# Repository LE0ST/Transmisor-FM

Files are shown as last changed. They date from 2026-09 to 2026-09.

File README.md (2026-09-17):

# Low-Power FM Broadcast Transmitter (88–108 MHz)

Low-power analog FM transmitter for the commercial VHF band (88–108 MHz). This project integrates analog RF stages, Altium Designer SPICE simulations, 4NEC2 antenna modeling, and an EasyEDA PCB implementation.

## Demonstration / Project Gallery

| 1. Physical Prototype (Assembled PCB) | 2. EasyEDA PCB 3D Design |
| :---: | :---: |
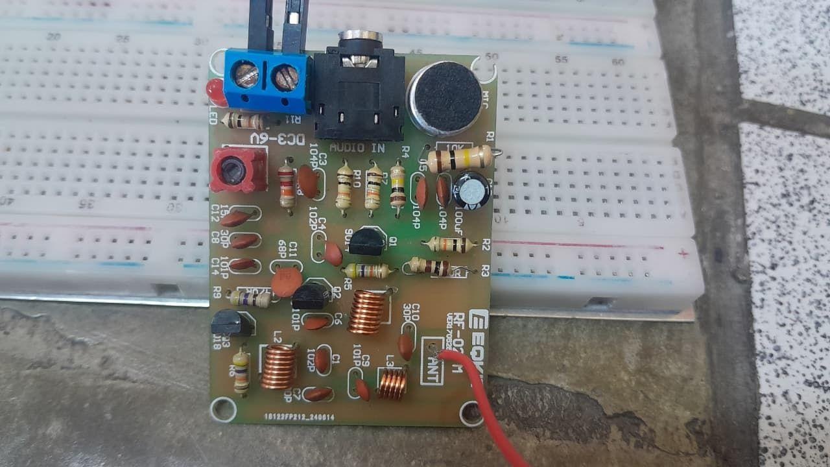
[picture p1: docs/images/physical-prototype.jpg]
Physical Prototype
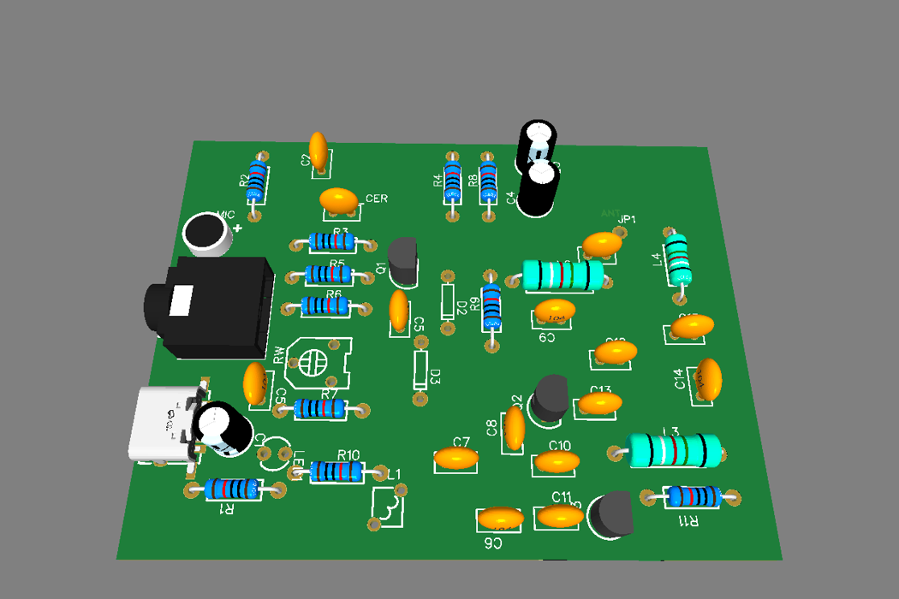
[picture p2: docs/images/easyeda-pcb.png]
EasyEDA PCB Design
|  |  |

| 3. RF Circuit Schematic | 4. 4NEC2 Antenna Radiation Pattern | 5. SPICE Transient Simulation |
| :---: | :---: | :---: |
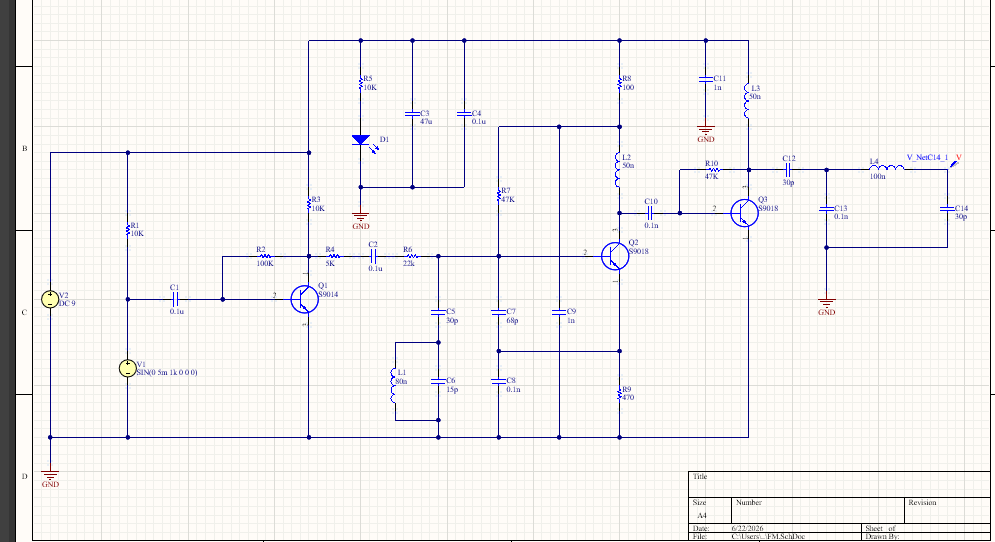
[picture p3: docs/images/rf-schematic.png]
RF Schematic
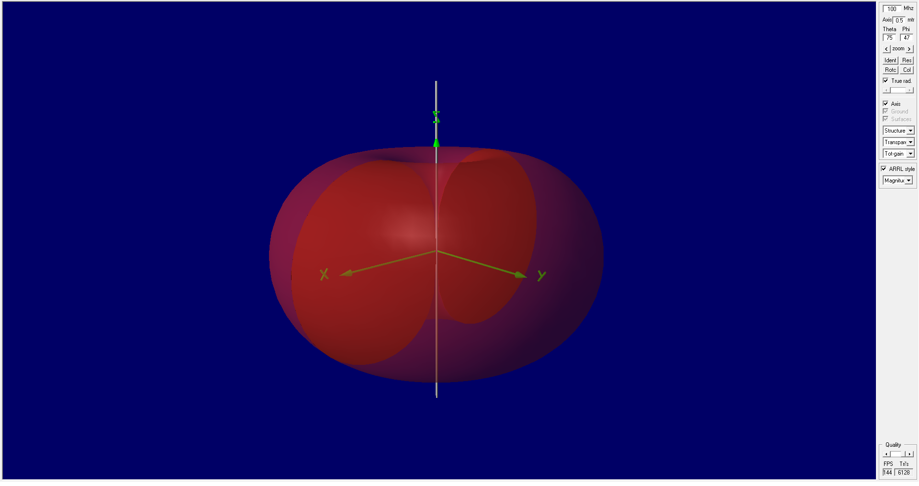
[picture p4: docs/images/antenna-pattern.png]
Antenna Pattern
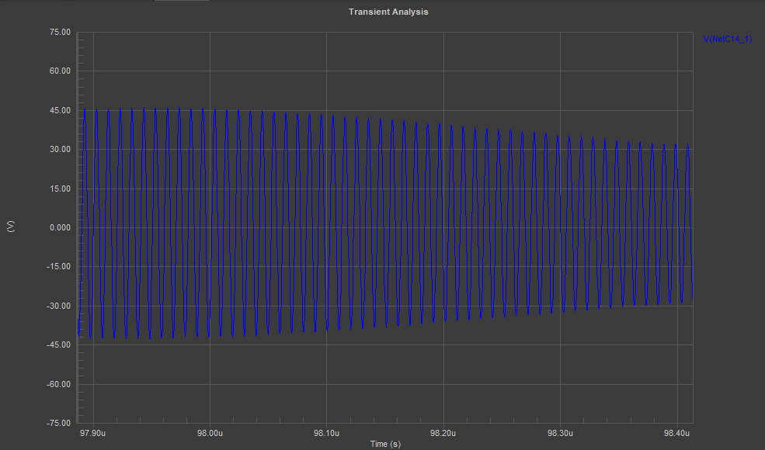
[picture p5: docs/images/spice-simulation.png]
SPICE Simulation
|  |  |  |

## Project Overview

This system was designed, simulated, and physically implemented to transmit audio over the commercial FM broadcast band. It is built with discrete analog components, operating from a 5 V power supply (Arduino Nano) and utilizing high-frequency bipolar junction transistors (BJTs).

## System Architecture

```mermaid
flowchart LR
    A[Audio Input] --> B[S9014 Common-Emitter Preamplifier]
    B --> C[S9018 Colpitts Oscillator / FM Modulator]
    C --> D[S9018 Class-C RF Amplifier]
    D --> E[Pi LC Output Network]
    E --> F[Antenna]
```

## RF Signal Chain

### 1. Audio Preamplifier
- **Topology:** Common-Emitter
- **Active Component:** S9014 (NPN BJT)
- **Performance:** Provides a theoretical voltage gain of approximately Av ≈ 49.3 dB at the 9 V design operating point.

### 2. Colpitts Oscillator & FM Modulator
- **Topology:** Colpitts LC Oscillator
- **Active Component:** S9018 (NPN RF BJT)
- **Modulation:** Direct reactive FM modulation via base-emitter junction capacitance variation.
- **Performance:** Theoretical frequency of 84.116 MHz (CALCULATED), tuned physically to 94.6 MHz (OBSERVED) in the prototype. Theoretical FM sensitivity calculated as kf ≈ 66.08 kHz/V.

### 3. Class-C RF Amplifier
- **Topology:** Common-Emitter with inductive collector load (Class-C)
- **Active Component:** S9018 (NPN RF BJT)
- **Function:** Class-C RF amplification stage intended to improve isolation from load variations.

### 4. Pi LC Output Network
- **Topology:** Passive Pi LC bandpass filter
- **Performance:** Designed for a theoretical center frequency of f0 = 101.94 MHz and a theoretical bandwidth of 19.89 MHz (CALCULATED), targeting a nominal 50 Ω load match.

### 5. Antenna
- **Design:** Modeled as a theoretical half-wave dipole at 100 MHz in 4NEC2 (SIMULATED).
- **Physical Test:** Field range tests utilized a monopole antenna (OBSERVED).

## Theoretical vs Simulated vs Experimental Results

| Parameter | Value | Evidence Type | Source |
|---|---|---|---|
| Operating target band | 88–108 MHz | DESIGN SPECIFICATION | Project Requirements |
| Theoretical oscillator frequency | 84.116 MHz | CALCULATED | Analytical Model |
| SPICE oscillator frequency | 100 MHz | SIMULATED | Altium SPICE |
| Physical prototype frequency | 94.6 MHz | OBSERVED | Commercial FM receiver |
| Audio voltage gain (Av) | 49.3 dB | CALCULATED at 9 V design point | Analytical Model |
| FM sensitivity (kf) | 66.08 kHz/V | CALCULATED | Analytical Model |
| Theoretical RF output power | 74.28 mW | CALCULATED | Analytical Model |
| Friis analysis transmit-power assumption | ~60 mW | ESTIMATED / ASSUMED | Theoretical analysis |
| SPICE RF output power | 6.57 mW | SIMULATED | Altium SPICE |
| Pi network center frequency | 101.94 MHz | CALCULATED | Analytical Model |
| Pi network bandwidth | 19.89 MHz | CALCULATED | Analytical Model |
| 4NEC2 dipole length | 1.425 m | SIMULATION MODEL | 4NEC2 DIPOLE.nec |
| 4NEC2 gain | 2.14 dBi | SIMULATED | 4NEC2 |
| 4NEC2 VSWR | 1.506 | SIMULATED | 4NEC2 |
| 4NEC2 return loss | 13.884 dB | SIMULATED | 4NEC2 |
| Observed reception range | up to approximately 50 m | OBSERVED with commercial FM receiver | Field observation |

## SPICE Simulation
Circuit and SPICE simulations were performed in **Altium Designer**. Mixed-signal simulations including Transient, AC Sweep, and Fourier analyses were used to characterize each stage's frequency response, gain, and spectral content.

## Antenna Modeling with 4NEC2
The radiation characteristics of a half-wave dipole were modeled using **4NEC2**. The theoretical simulation model exhibited a total length of 1.425 m, yielding a simulated gain of 2.14 dBi, a VSWR of 1.506, and a return loss of 13.884 dB at 100 MHz in free space. Field tests used a physical monopole antenna.

## PCB Design & Fabrication
The PCB was designed in **EasyEDA**. Manufacturing Gerbers were exported, and the physical board was fabricated using a phenolic copper-clad board and ferric chloride etching. The board was then hand-assembled and soldered. *(Note: The original EasyEDA editable design files are not currently archived in this repository; only the Gerber manufacturing outputs are included.)*

## Physical Prototype
The physical prototype was powered by a 5 V supply from an Arduino Nano.

## Experimental Observations
During physical validation:
- The supply voltage was confirmed at 5 V with a multimeter.
- The transmitter was tuned to approximately 94.6 MHz.
- FM audio reception was observed up to approximately 50 m using a commercial FM receiver.

## Technical Documentation

The complete sanitized technical report is available here:

[View the Technical Report (PDF)](docs/Informe_Tecnico_Transmisor_FM_PUBLIC.pdf)

The public version preserves the engineering content while removing private academic identifiers.

## Bill of Materials
| Component | Value/Part | Stage |
|---|---|---|
| Transistor | S9014 | Audio Preamp |
| Transistor | S9018 | Oscillator & RF Amp |
| Inductor | Adjustable Ferrite Core | LC Tank |
| Inductor | Fixed RF Inductors | Buffer & Filter |
| Capacitors | Ceramic (various) | Signal Coupling, Tank, Filter |
| Resistors | Carbon Film (various) | Biasing |
| PCB | Phenolic copper-clad | Base |

## Repository Structure
```text
low-power-fm-transmitter/
├── docs/
│   ├── Informe_Tecnico_Transmisor_FM_PUBLIC.pdf
│   └── images/
├── hardware/
│   ├── altium/
│   └── fabrication/gerber/
├── simulation/
│   ├── antenna_4nec2/
│   ├── captures/
│   └── spice/
└── README.md
```

## Engineering Limitations
- **Frequency Pulling:** While the Class-C buffer was intended to isolate the oscillator, frequency pulling was still observed in the physical prototype, indicating that isolation was incomplete.
- **Power Supply Mismatch:** Design calculations assumed a 9 V supply, whereas the physical prototype operated at 5 V, leading to differences between theoretical operating points and physical behavior.
- **Antenna Divergence:** While a half-wave dipole was simulated in 4NEC2, a telescopic monopole was utilized for physical range tests.
- **Instrument Limitations:** Direct RF output power, spectral purity, and antenna impedance/VSWR were not characterized with an RF power meter, oscilloscope, or spectrum analyzer.

## Academic Context & Authors
This project was developed as a seven-member university group project for the Analog Communications course in Electronic Engineering at Universidad Nacional Mayor de San Marcos (UNMSM).

**Authors:**
- Purihuamán Rivera, Juan Matías
- Saenz Burga, Alexander Ricardo
- Yactayo Tolentino, Leonardo Sait
- Mestanza Salazar, Elias Fernando
- Huaraca Pariona, Jose Miguel
- Gamarra Galarza, Nayely Dayana
- Condori Ancco, Marco Antonio

*(Individual contribution breakdown is not established by the repository history.)*

## License

Licensing terms have not yet been specified.

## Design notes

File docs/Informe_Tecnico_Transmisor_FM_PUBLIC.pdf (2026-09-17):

## Universidad Nacional Mayor de San Marcos

Universidad del Perú, Decana de América Facultad de Ingeniería Electrónica & Eléctrica Escuela Académica Profesional de Ingeniería Electrónica

Mg. Hansel Martínez Odiaga | Página N°01 | 2026—I

## COMUNICACIÓN ANALÓGICA

### TRABAJO ACADÉMICO

PROYECTO FINAL DE INVESTIGACIÓN E IMPLEMENTACIÓN DE TRANSMISOR FM

## Integrantes

APELLIDOS & NOMBRES | CÓDIGO | GRUPO
Purihuamán Rivera, Juan Matías | [REDACTED] | N°01
Saenz Burga, Alexander Ricardo | [REDACTED]
Yactayo Tolentino, Leonardo Sait | [REDACTED]
Mestanza Salazar, Elias Fernando | [REDACTED]
Huaraca Pariona, Jose Miguel | [REDACTED]
Gamarra Galarza, Nayely Dayana | [REDACTED]
Condori Ancco, Marco Antonio | [REDACTED]

## Universidad Nacional Mayor de San Marcos

Universidad del Perú, Decana de América Facultad de Ingeniería Electrónica & Eléctrica Escuela Académica Profesional de Ingeniería Electrónica

Mg. Hansel Martínez Odiaga | Página N°02 | 2026—I

ÍNDICE GENERAL

## Universidad Nacional Mayor de San Marcos

Universidad del Perú, Decana de América Facultad de Ingeniería Electrónica & Eléctrica Escuela Académica Profesional de Ingeniería Electrónica

Mg. Hansel Martínez Odiaga | Página N°03 | 2026—I

## Universidad Nacional Mayor de San Marcos

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

Mg. Hansel Martínez Odiaga | Página N°04 | 2026—I

## Universidad Nacional Mayor de San Marcos

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

Mg. Hansel Martínez Odiaga | Página N°05 | 2026—I

## Universidad Nacional Mayor de San Marcos

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

Mg. Hansel Martínez Odiaga | Página N°06 | 2026—I

## Universidad Nacional Mayor de San Marcos

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

Mg. Hansel Martínez Odiaga | Página N°07 | 2026—I
13.— Etapa de Amplificación RF | 136
Bloque N°04.1: Filtro de Salida | 141
14.— Etapa Filtro de Acoplamiento | 141
Bloque N°04.2: Antena Transmisora | 146
15.— Diseño de Antena Transmisora | 146
PROCEDIMIENTO DE IMPLEMENTACIÓN | 154
Entorno de Diseño EasyEDA | 154
¿Para qué se utiliza? | 154
¿Cuáles son sus ventajas principales? | 154
Bloque N°01: Fuente de Audio + Preamplificador de Audio | 161
Bloque N°02: Oscilador RF + Modulador FM | 162
Bloque N°03: Etapa Buffer + Amplificador RF | 163
Bloque N°04: Filtro de Salida + Antena Transmisora | 164
MEDICIONES EXPERIMENTALES | 166
Bloque N°01: Fuente de Audio + Preamplificador de Audio | 166
Medición de Fuente de Alimentación | 166
Bloque N°02: Oscilador RF + Modulador FM | 168
Medición de Frecuencia de Oscilación | 168
Bloque N°03: Etapa Buffer + Amplificador RF | 170
Medición de Potencia de Transmisión | 170
Propagación en el Espacio Libre | 170
Bloque N°04: Filtro de Salida + Antena Transmisora | 174
Medición de Potencia de Recepción | 174
RESULTADOS DE DISEÑO | 178
Bloque N°01: Fuente de Audio + Preamplificador de Audio | 178
— Enfoque Teórico | 178
— Enfoque Simulado | 178
— Enfoque Implementado | 178
Bloque N°02: Oscilador RF + Modulador FM | 179
— Enfoque Teórico | 179
— Enfoque Simulado | 179
— Enfoque Implementado | 179

## Universidad Nacional Mayor de San Marcos

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

Mg. Hansel Martínez Odiaga | Página N°08 | 2026—I
Bloque N°03: Etapa Buffer + Amplificador RF | 180
— Enfoque Teórico | 180
— Enfoque Simulado | 180
— Enfoque Implementado | 180
Bloque N°04: Filtro de Salida + Antena Transmisora | 181
— Enfoque Teórico | 181
— Enfoque Simulado | 181
— Enfoque Implementado | 181
ANÁLISIS & DISCUSIÓN DE RESULTADOS | 182
Bloque N°01: Fuente de Audio + Preamplificador de Audio | 182
— Acoplamiento e Impedancia de Entrada | 182
— Respuesta en Frecuencia. Fidelidad del Canal | 182
— Relación Señal/Ruido. Pre—Énfasis | 182
Bloque N°02: Oscilador RF + Modulador FM | 183
— Estabilidad de Frecuencia Portadora Central | 183
— Linealidad. Sensibilidad de Modulación | 183
— Desviación de Frecuencia. Sobremodulación | 183
Bloque N°03: Etapa Buffer + Amplificador RF | 184
— Aislamiento de la Etapa Buffer Vs. Efecto Pulling | 184
— Eficiencia Energética Vs. Linealidad en Clase C | 184
— Generación del Contenido Armónico de Potencia | 184
Bloque N°04: Filtro de Salida + Antena Transmisora | 185
— Supresión de Emisiones Espurias/Armónicas | 185
— Adaptación de Impedancias. Pérdida de Retorno | 185
— Relación de Onda Estacionaria (VSWR). Alcance Experimental | 185
CONCLUSIONES & RECOMEDACIONES | 186
1.— Conclusión General | 186
2.— Conclusiones Específicas | 186
3.— Recomendaciones | 187
REFERENCIAS BIBLIOGRÁFICAS | 188
ANEXOS | 189

## Universidad Nacional Mayor de San Marcos

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

Mg. Hansel Martínez Odiaga | Página N°09 | 2026—I

INTRODUCCIÓN

La Modulación en Frecuencia (FM) es uno de los pilares fundamentales en el desarrollo de los sistemas de Comunicación Analógica, destacando una excelente calidad de audio o una alta inmunidad frente al ruido e interferencias en comparación con otras técnicas como la Modulación en Amplitud (AM). En el ámbito de la formación en Ingeniería Electrónica, el estudio de este proceso no se limita con la comprensión de variables o abstracciones matemáticas, sino que nos exige una asimilación práctica de Fenómenos de RF, Propagación de Ondas EM o de Electrónica Analógica. Por lo tanto, la exploración de este sistema nos permite la consolidación de una base para el diseño de tecnologías más avanzadas.

OBJETIVOS

1.— Objetivo General

Diseñar e implementar experimentalmente un prototipo funcional de Transmisor FM que opere en baja potencia, aplicando estrictamente los fundamentos teóricos de nuestro curso de Comunicación Analógica para asegurar una transmisión inalámbrica de señales de audio con la mínima variación de frecuencia dentro de la banda comercial FM, garantizando la máxima fidelidad en la señal transmitida.

2.— Objetivos Específicos

2.1.— Analizar matemáticamente los principios de Modulación FM como los bloques funcionales del Transmisor FM. Esto involucra el cálculo del índice de modulación, desviación de frecuencia o del ancho de banda mediante la Regla de Carson, como el dimensionamiento base de las etapas de Preamplificación de Audio, Oscilador RF, Modulador/Buffer, Amplificador RF, Filtros LC.

2.2.— Simular el comportamiento del TX FM mediante las herramientas de software especializadas antes del ensamblaje físico. Este proceso tiene como finalidad verificar la Estabilidad de Oscilación, Respuesta Espectral Modulada, Sensibilidad de Modulación, Potencia de Salida especificada hasta ∼100 mW, garantizando que nuestro diseño cumpla con los criterios técnicos requeridos antes de la fabricación del Circuito Impreso (PCB), el cual es necesario para demostrar su funcionamiento.

2.3.— Implementar el sistema electrónico resultante en tarjeta de Circuito Impreso, evaluando su desempeño real mediante Instrumentación de Laboratorio. Con esto demostramos la transmisión efectiva de audio con rango de alcance(10—50) m, realizando mediciones críticas de Frecuencia de

## Universidad Nacional Mayor de San Marcos

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

Mg. Hansel Martínez Odiaga | Página N°010 | 2026—
I

Operación, Amplitud FM como verificando su comportamiento en el Osciloscopio Digital para la comparación precisa de todos los Resultados Teóricos, Simulados, Experimentales obtenidos.

## Universidad Nacional Mayor de San Marcos

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

Mg. Hansel Martínez Odiaga | Página N°10 | 2026—I

MARCO TEÓRICO

1.— Modulación FM

La Modulación en Frecuencia (FM) es una técnica de transmisión analógica en la cual la señal de audio (como la voz o la música) modifica directamente la velocidad de oscilación de una onda portadora de alta frecuencia. En este proceso, la amplitud de la portadora se mantiene completamente constante, lo que significa que la potencia de la señal no cambia durante la transmisión. En su lugar, es la frecuencia de la portadora la que varía continuamente, acelerándose o desacelerándose en perfecta sincronía con los cambios de voltaje de la señal de audio original. Esta característica es la que le otorga al sistema una alta fidelidad o gran inmunidad frente a las diversas interferencias estáticas o ruido atmosférico, dado que estas perturbaciones afectan directamente a la amplitud de la onda portadora, no a su frecuencia.

1.1.— Fundamento de Modulación FM

1.1.1— Ecuación General

Toda Onda Senoidal Continua (CW) se representa mediante un ángulo θ(t).

La frecuencia instantánea wi(t) se define como la tasa de cambio del ángulo.

Consideremos que la frecuencia instantánea wi(t) es proporcional a la señal de entrada f(t).

Luego, se obtiene una determinada expresión para el ángulo θ(t).

## Universidad Nacional Mayor de San Marcos

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

Mg. Hansel Martínez Odiaga | Página N°11 | 2026—I

Entonces, se define la expresión de la señal modulada FM.

1.1.2— Parámetros Generales

Consideremos que la señal de entrada f(t) es un tono puro.

Luego, se obtiene la expresión de la frecuencia instantánea wi(t).

Donde:
kf [(rad/s)/V] representa la Constante de Modulación FM. Δw [rad/s] representa la Desviación de Frecuencia Pico.

Entonces, se sostiene la expresión para el ángulo θ(t).

## Universidad Nacional Mayor de San Marcos

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

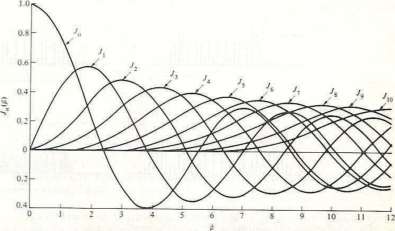
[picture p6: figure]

Mg. Hansel Martínez Odiaga | Página N°12 | 2026—I

Donde:
β representa el Índice de Modulación FM.

Finalmente, se define la expresión de la señal modulada FM.

Donde:
Jn(β) representa la Función de Bessel de primera clase de orden n—ésimo, de argumento β.

Figura N°01_ Gráficas de Función de Bessel de primera clase Jn(β)

## Universidad Nacional Mayor de San Marcos

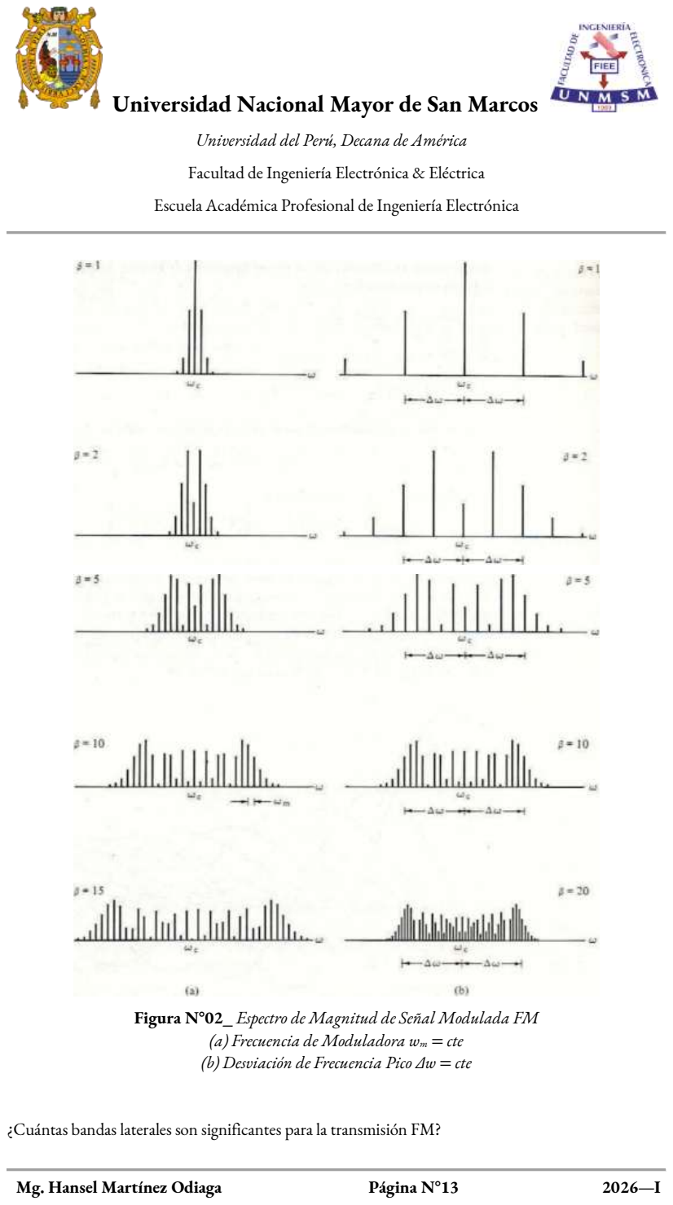
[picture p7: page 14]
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

Mg. Hansel Martínez Odiaga | Página N°13 | 2026—I

Figura N°02_ Espectro de Magnitud de Señal Modulada FM
(a) Frecuencia de Moduladora wm = cte
(b) Desviación de Frecuencia Pico Δw = cte

¿Cuántas bandas laterales son significantes para la transmisión FM?

## Universidad Nacional Mayor de San Marcos

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

Mg. Hansel Martínez Odiaga | Página N°14 | 2026—I

El ancho de banda queda definido para Modulación FM de Banda Angosta (NBFM).

El ancho de banda queda definido para Modulación FM de Banda Ancha (WBFM).

El ancho de banda según la Regla de Carson queda definido para casos intermedios.

La potencia promedio de la señal portadora queda definida mediante J0(β).

La potencia promedio de las bandas laterales queda definida mediante Jn(β).

## Universidad Nacional Mayor de San Marcos

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

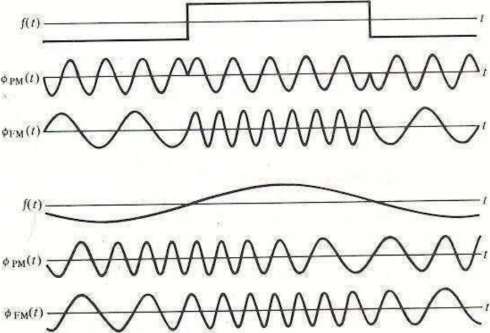
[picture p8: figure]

Mg. Hansel Martínez Odiaga | Página N°15 | 2026—I

La potencia promedio total queda definida mediante la señal portadora.

Figura N°03_ Modulación en Frecuencia Vs. Modulación en Fase

2.— Oscilador LC

## Universidad Nacional Mayor de San Marcos

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

Mg. Hansel Martínez Odiaga | Página N°16 | 2026—I

Un oscilador LC es un circuito electrónico diseñado para generar señales de radiofrecuencia senoidales mediante la transferencia cíclica de energía entre un capacitor e inductor. Al conectar los componentes en paralelo, el capacitor almacena energía como campo eléctrico; luego, la descarga hacia el inductor, el cual almacena dicha energía como campo magnético que, luego, colapsa para recargar al capacitor en sentido opuesto. Este intercambio continuo da origen a una oscilación con frecuencia de resonancia gobernada por los valores de la inductancia/capacitancia del diseño. No obstante, debido a las pérdidas resistivas inherentes en componentes reales, estas oscilaciones tienden a amortiguarse, por lo que este circuito requiere una etapa amplificadora con retroalimentación positiva que reinyecte continuamente la energía perdida, garantizando la señal portadora natural estable dentro de la banda de transmisión.

Figura N°04_ Criterio de Oscilación de Barkhausen

2.1.— Oscilador LC Sintonizante

2.1.1.— Oscilador LC Sintonizante Colpitts

El oscilador Colpitts es una variante específica de los osciladores LC que destaca por su alta estabilidad en alta frecuencia, con un diseño característico de divisor de tensión capacitivo. En esta configuración, la red de realimentación en paralelo con el inductor (L) se divide en dos capacitores en serie (C1, C2), cuyo punto intermedio se conecta a GND. Esta disposición permite derivar una fracción exacta de la señal del colector mediante el capacitor de acoplo (CC) e inyectarla de vuelta hacia la base del transistor BJT con una ganancia, desfase necesarios para cumplir adecuadamente con el Criterio de Barkhausen.

## Universidad Nacional Mayor de San Marcos

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

Mg. Hansel Martínez Odiaga | Página N°17 | 2026—I

Figura N°05_ Oscilador Colpitts BJT: Esquemático, Frecuencia de Operación

## Universidad Nacional Mayor de San Marcos

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

Mg. Hansel Martínez Odiaga | Página N°18 | 2026—I

2.1.2.— Oscilador LC Sintonizante Hartley

El oscilador Hartley es una variante clásica de los osciladores LC que se identifica de forma directa por utilizar un divisor de tensión inductivo en su circuito tanque para establecer la red de realimentación. En esta configuración, la malla resonante en paralelo con el capacitor (C) se encuentra constituida por una bobina con derivación central o mediante dos inductores serie (L1, L2), cuyo punto de conexión intermedia se vincula a una referencia común. Esta disposición permite tomar una fracción de la señal de CA del colector para transferirla de vuelta hacia la base del transistor BJT a través del capacitor de acoplamiento (CC), logrando una ganancia/desfase necesarios para mantener una oscilación continua.

Figura N°06_ Oscilador Hartley BJT: Esquemático, Frecuencia de Operación

## Universidad Nacional Mayor de San Marcos

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

Mg. Hansel Martínez Odiaga | Página N°19 | 2026—I

2.2.— Oscilador LC Sintonizado

El oscilador de cristal es un sistema electrónico diseñado para generación de señales de portadora con una estabilidad de frecuencia excepcionalmente alta, superando drásticamente a los circuitos tanque LC convencionales mediante uso del elemento piezoeléctrico de cuarzo como componente resonante. Basado en el Efecto Piezoeléctrico, el cristal experimenta una distorsión mecánica cuando se le aplica cierto voltaje AC, estableciendo vibraciones electromecánicas para una frecuencia natural sumamente precisa que depende de sus dimensiones. Eléctricamente, su comportamiento se modela mediante una red equivalente conformada por una rama RLC en serie que representa la masa, fricción o elasticidad del cristal de cuarzo, acoplada en paralelo con una capacitancia de derivación (CM) propia del montaje físico. Dado que las pérdidas internas representadas por la resistencia de fricción son extremadamente bajas, el cristal posee un factor de calidad (Q) muy elevado que típicamente ronda valores desde 20 000 hasta 10⁶

, garantizando un espectro de salida libre de las desviaciones térmicas o derivas de frecuencia.

Figura N°07_ Cristal de Cuarzo: Circuito Equivalente

## Universidad Nacional Mayor de San Marcos

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

Mg. Hansel Martínez Odiaga | Página N°20 | 2026—I

2.2.1.— Oscilador LC Sintonizado Serie

El oscilador controlado por cristal en el modo serie aprovecha la condición de resonancia del circuito equivalente donde las reactancias de rama RLC interna se igualan/cancelan mutuamente, provocando que la impedancia general del cristal caiga a un valor mínimo absoluto. Al conectarse el cristal (XTAL) directamente en la rama de realimentación entre colector—base del transistor BJT, este actúa como un filtro selectivo que únicamente permite el paso de corriente a la frecuencia exacta de resonancia serie, punto en el cual la realimentación positiva hacia la etapa amplificadora se maximiza. Las resistencias de polarización (R1, R2, RE) junto con el capacitor de paso (CE) nos aseguran un punto de operación en corriente continua del transistor BJT, mientras que el choque de radiofrecuencia (RFC) en el colector actúa como carga de alta impedancia en CA, permitiendo que el circuito sostenga oscilaciones estables limitadas estrictamente por la frecuencia serie del cuarzo, estabilizando una portadora de modulación.

Figura N°08_ Oscilador LC Sintonizado: Cristal de Cuarzo Serie

## Universidad Nacional Mayor de San Marcos

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

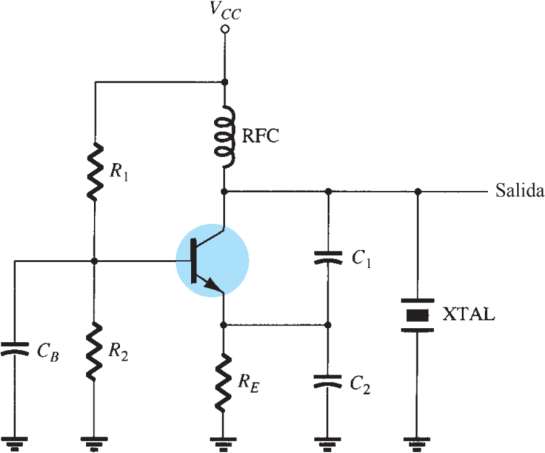
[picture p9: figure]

Mg. Hansel Martínez Odiaga | Página N°21 | 2026—I

2.2.2.— Oscilador LC Sintonizado Paralelo

El oscilador controlado por cristal en el modo paralelo, frecuentemente diseñado sobre una topología modificada de Colpitts, opera a una frecuencia ligeramente superior a la de resonancia en serie, justo en el punto de antirresonancia donde la reactancia de la rama inductiva equivalente interactúa con la capacitancia de derivación (CM) para elevar la impedancia base del cristal en un valor máximo. En esta configuración, el cristal (XTAL) se conecta en derivación hacia GND en paralelo mediante una red de realimentación constituida por el divisor capacitivo (C1, C2), actuando eficazmente como un inductor sintonizado con un alto valor de Q. La señal oscilante del colector se acopla a la red de realimentación; luego, se reinyecta hacia la base del transistor —que se encuentra a masa para CA mediante el capacitor de desacoplo CB— permitiendo que nuestro sistema aproveche la pendiente pronunciada de la curva de impedancia inductiva/cristal para corregir inmediatamente un intento de desviación de frecuencia.

Figura N°09_ Oscilador LC Sintonizado: Cristal de Cuarzo Paralelo

## Universidad Nacional Mayor de San Marcos

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

Mg. Hansel Martínez Odiaga | Página N°22 | 2026—I

Figura N°10_ Cristal de Cuarzo: Impedancia Vs. Frecuencia de Resonancia Frecuencia de Resonancia Serie: f1 Frecuencia de Resonancia Paralelo (Antirresonancia): f2

## Universidad Nacional Mayor de San Marcos

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

Mg. Hansel Martínez Odiaga | Página N°23 | 2026—I

3.— Amplificación de Potencia RF

Un amplificador de potencia RF es un circuito electrónico diseñado con el objetivo de elevar el nivel de energía de una señal de alta frecuencia para que pueda ser transmitida a través de una antena hacia el espacio libre. A diferencia de los amplificadores de pequeña señal, que se optimizan para maximizar la ganancia de voltaje sin deformar la señal, los amplificadores de potencia se diseñan para transferir la máxima cantidad de corriente/voltaje hacia carga de baja impedancia (habitualmente 50 Ω), buscando el mejor compromiso posible entre linealidad/eficiencia en el sistema. Dependiendo de la polarización en corriente continua (CC) aplicada hacia la compuerta o base del transistor, el circuito opera en una clase de amplificación específica (A, B o C), la cual nos define el tiempo que el dispositivo permanece encendido, dictando directamente el rendimiento térmico o el nivel de distorsión armónica presente.

3.1.— Amplificador de Potencia RF Clase A

3.1.1.— Fundamento del Amplificador de Potencia RF Clase A

El amplificador Clase A es la configuración de potencia más elemental/lineal en RF, caracterizada por mantener al transistor en una conducción continua durante la totalidad del ciclo de señal de entrada. Para lograr esto, se fija un punto de operación quiescente (Q) elevado en el centro de la recta de carga (con corriente Idd no nula), de modo que la excursión de la señal nunca sature ni corte al componente activo, entregando una réplica de salida sinusoidal matemáticamente fiel e ideal para los esquemas de modulación que varían en amplitud. No obstante, al demandar corriente constante directamente de la fuente de alimentación (VDD) incluso en ausencia de señal de entrada, este circuito disipa una enorme cantidad de energía en la forma de calor, limitando drásticamente su rendimiento energético teórico.

Figura N°11_ Amplificador de Potencia RF Clase A: Esquemático, Curva Característica

## Universidad Nacional Mayor de San Marcos

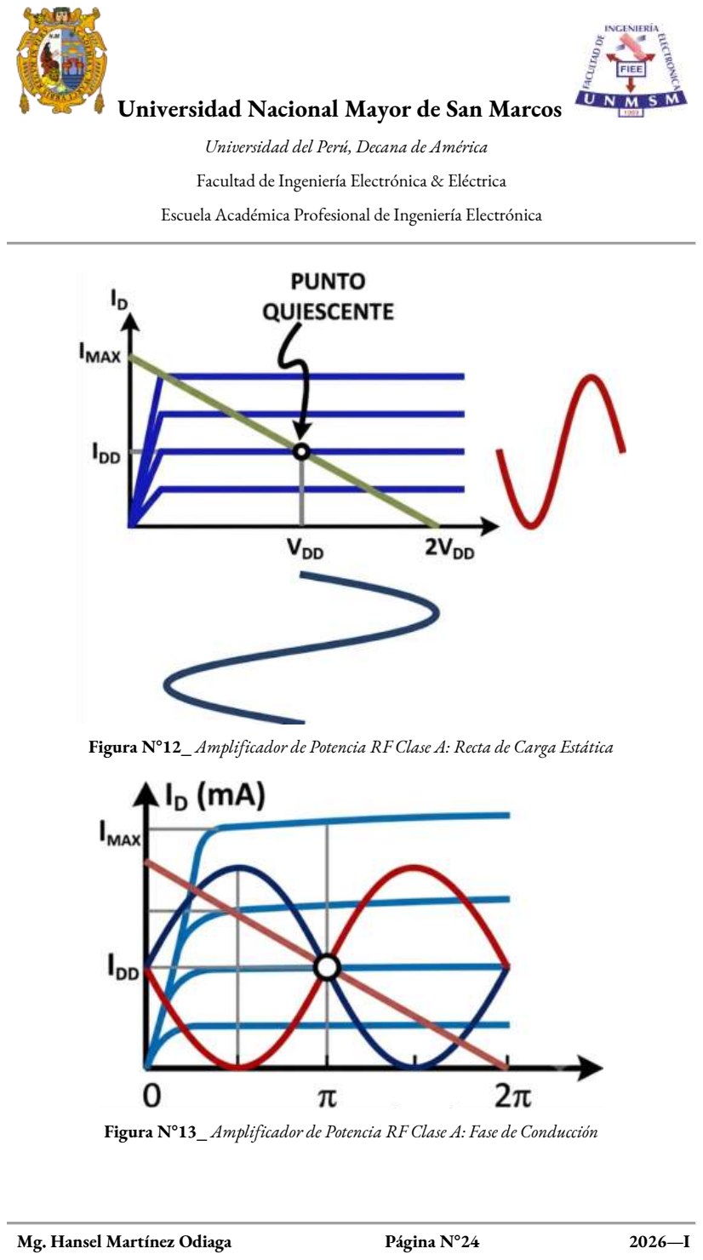
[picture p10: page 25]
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

Mg. Hansel Martínez Odiaga | Página N°24 | 2026—I

Figura N°12_ Amplificador de Potencia RF Clase A: Recta de Carga Estática

Figura N°13_ Amplificador de Potencia RF Clase A: Fase de Conducción

## Universidad Nacional Mayor de San Marcos

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

Mg. Hansel Martínez Odiaga | Página N°25 | 2026—I

3.1.2.— Parámetros del Amplificador de Potencia RF Clase A

— Fase de Conducción
Conduce de forma continua durante todo el ciclo.

— Potencia Promedio DC
Potencia de corriente continua suministrada por la fuente de alimentación.

— Potencia de Salida AC
Potencia de corriente alterna entregada hacia la carga.

— Eficiencia de Amplificación
Rendimiento teórico máximo alcanzado con carga sintonizada.

3.2.— Amplificador de Potencia RF Clase B

## Universidad Nacional Mayor de San Marcos

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

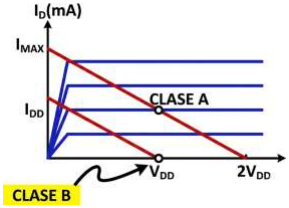
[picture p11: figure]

Mg. Hansel Martínez Odiaga | Página N°26 | 2026—I

3.2.1.— Fundamento del Amplificador de Potencia RF Clase B

El amplificador Clase B se diseña con el propósito de mitigar las pérdidas por disipación térmica de la Clase A mediante el desplazamiento base del punto de operación quiescente justo en el límite del corte del transistor, donde la corriente de polarización en reposo es idealmente nula. Bajo esta condición, el componente activo funciona como un rectificador de media onda que solo conduce corriente durante el semiciclo positivo de la entrada, apagándose por completo en el semiciclo opuesto. Para aplicaciones de audio o RF de banda ancha, dicho comportamiento requiere obligatoriamente un diseño simétrico de dos transistores acoplados en contrafase (push—pull) para que cada uno amplifique una mitad de la onda; sin embargo, en aplicaciones puras de RF sintonizada de banda estrecha, es viable utilizar solo un transistor siempre que se incorpore el circuito tanque resonante a la salida para que actúe como un volante de control de potencia en la reconstrucción de la componente armónica fundamental perdida.

Figura N°14_ Amplificador de Potencia RF Clase B: Esquemático, Curva Característica

## Universidad Nacional Mayor de San Marcos

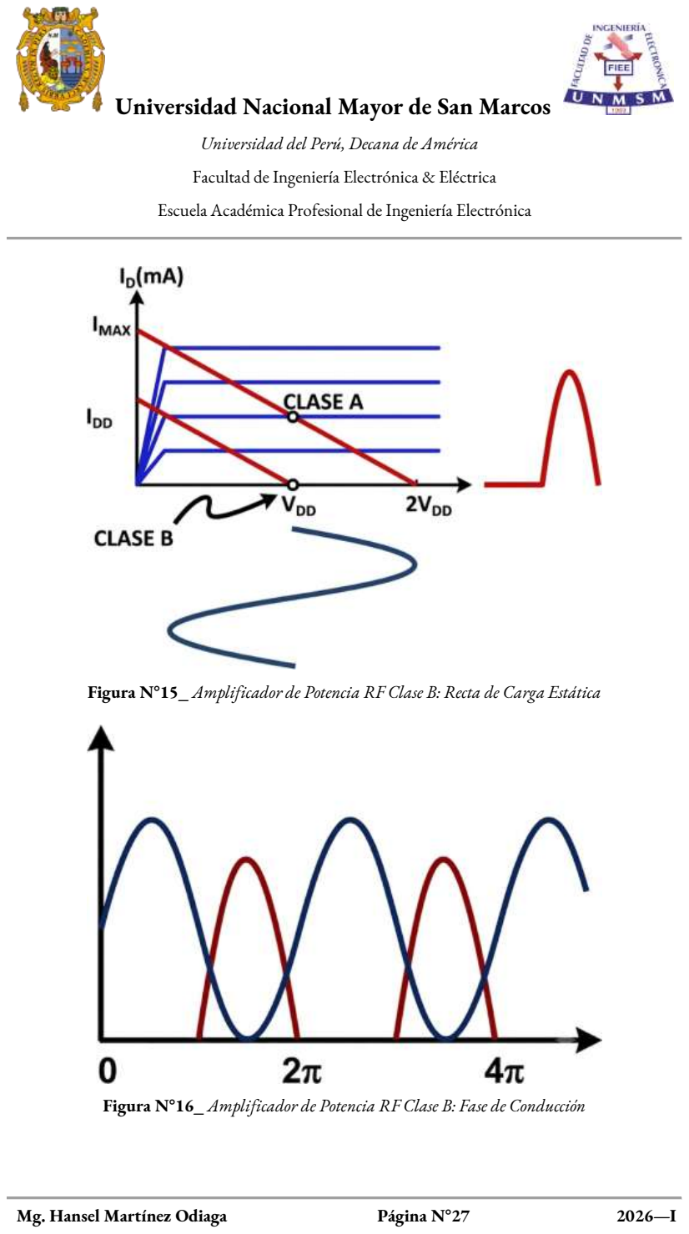
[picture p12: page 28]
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

Mg. Hansel Martínez Odiaga | Página N°27 | 2026—I

Figura N°15_ Amplificador de Potencia RF Clase B: Recta de Carga Estática

Figura N°16_ Amplificador de Potencia RF Clase B: Fase de Conducción

## Universidad Nacional Mayor de San Marcos

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

Mg. Hansel Martínez Odiaga | Página N°28 | 2026—I

3.2.2.— Parámetros del Amplificador de Potencia RF Clase B

— Fase de Conducción
Conduce precisamente durante medio ciclo.

— Potencia Promedio DC
Potencia de corriente continua suministrada por la fuente de alimentación.

— Potencia de Salida AC
Potencia de corriente alterna entregada hacia la carga.

— Eficiencia de Amplificación
Rendimiento teórico máximo alcanzado con carga sintonizada.

3.3.— Amplificador de Potencia RF Clase C

## Universidad Nacional Mayor de San Marcos

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

Mg. Hansel Martínez Odiaga | Página N°29 | 2026—I

3.3.1.— Fundamento del Amplificador de Potencia RF Clase C

El amplificador Clase C está optimizado con un enfoque puramente orientado al alto rendimiento, su máxima eficiencia energética presente en sistemas de transmisión de alta frecuencia. En este circuito, el transistor se polariza intencionalmente en inversa (Vbias < VT), obligando a que el punto quiescente se ubique profundamente metido en la zona de corte del dispositivo. Como una consecuencia directa, el componente activo únicamente reacciona ante picos máximos positivos para la entrada, conduciendo corriente en forma de un tren de pulsos angostos, altamente distorsionados, que carecen de cualquier relación lineal con la amplitud del mensaje original. Esta severa distorsión exige de forma mandatoria la adición de un filtro de salida resonante LC Pasabanda de alto factor de calidad (Q), el cual almacena la energía de los pulsos, cortocircuitando los armónicos no deseados, logrando recuperar la portadora.

Figura N°17_ Amplificador de Potencia RF Clase C: Esquemático

3.3.2.— Parámetros del Amplificador de Potencia RF Clase C

## Universidad Nacional Mayor de San Marcos

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

Mg. Hansel Martínez Odiaga | Página N°30 | 2026—I

— Fase de Conducción
Conduce durante un intervalo estrecho o menos de medio ciclo.

— Potencia Promedio DC
Potencia de corriente continua suministrada por la fuente de alimentación.

— Potencia de Salida AC
Potencia de corriente alterna entregada hacia la carga.

— Eficiencia de Amplificación
Rendimiento teórico máximo alcanzado con carga sintonizada.

4.— Adaptación de Impedancias

4.1.— Acoplamiento de Líneas Bifilares

## Universidad Nacional Mayor de San Marcos

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

Mg. Hansel Martínez Odiaga | Página N°31 | 2026—I

4.1.1.— Acoplamiento con Transformador de Cuarto de Onda

Las propiedades de las líneas de transmisión de longitud λ/4 (transformador de λ/4) pueden utilizarse para adaptar la impedancia de un dipolo (Za) a la de una línea (Z0). Luego, la impedancia característica del transformador (Z0λ/4) se encuentra dada mediante la relación:

De modo que, una vez determinada Z0λ/4, solo se debe escoger los valores apropiados para la separación de los conductores como también la longitud de sus radios que satisfagan la expresión de impedancia característica de una línea bifilar de sección transversal circular; esto es, que se cumpla la relación:

Donde:
D [m] representa la separación entre los ejes de los conductores. a [m] representa la longitud del radio de los conductores.

Figura N°18_ Sección Transversal de una Línea Bifilar

## Universidad Nacional Mayor de San Marcos

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

Mg. Hansel Martínez Odiaga | Página N°32 | 2026—I

Figura N°19_ Acoplamiento con Transformador de Cuarto de Onda

4.1.2.— Acoplamiento en Delta

Experimentalmente, se ha encontrado que la impedancia entre los puntos de alimentación del dipolo de media onda varía al variar simétricamente la posición de los puntos de alimentación con respecto a su punto central; luego, al disminuir la separación entre dichos puntos disminuirá la impedancia. Esta característica se utiliza para acoplar una línea bifilar al dipolo. La dimensión c representa la separación entre los puntos de alimentación, mientras que la dimensión b representa la distancia hacia la línea de transmisión; dichas cantidades, para Z0 = 600 Ω, cumplen las siguientes relaciones:

Figura N°20_ Acoplamiento en Delta

## Universidad Nacional Mayor de San Marcos

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

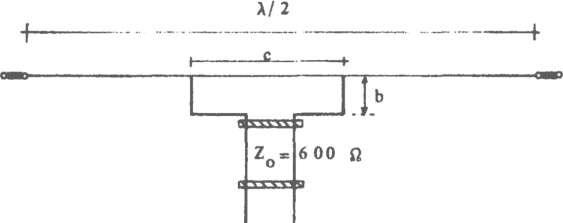
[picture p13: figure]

Mg. Hansel Martínez Odiaga | Página N°33 | 2026—I

4.1.3.— Acoplamiento en T

El acoplamiento en T se basa en el mismo principio que el acoplamiento en delta.

Figura N°21_ Acoplamiento en T

Las dimensiones conocidas b, c se encuentran determinadas por la impedancia característica de la línea; de manera experimental, para una impedancia de línea Z0 = 600 Ω, cumplen las siguientes relaciones:

Este tipo de acoplo tiene el inconveniente de que su impedancia, además de una componente resistiva, tiene una componente reactiva (inductiva), la cual debemos eliminar para una adecuada adaptación. La cancelación de la reactancia inductiva del acoplamiento se puede lograr acortando la antena hasta obtener una reactancia capacitiva que la cancele, o insertando ciertos capacitores de valor apropiado.

## Universidad Nacional Mayor de San Marcos

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

Mg. Hansel Martínez Odiaga | Página N°34 | 2026—I

Figura N°22_ Acoplamiento en T con Capacitores en Serie

4.1.4.— Acoplamiento Gamma

El acoplamiento gamma es un caso particular del acoplamiento en T, aunque se utilizan conductores coaxiales por tratarse de un sistema desbalanceado. Para cancelar la reactancia inductiva que presenta, se utiliza el mismo procedimiento que para el acoplamiento en T.

Figura N°23_ Acoplamiento Gamma con Capacitores en Serie

Este acoplamiento se usa, generalmente, para acoplar un conductor coaxial a dipolos construidos con tubos de aluminio (VHF, UHF). Debido a que son múltiples los factores que intervienen en el cálculo del acoplamiento, lo que comúnmente se hace es hallar los valores de la forma experimental. Entonces, para adaptar un dipolo de tubo de aluminio de 52 Ω, la longitud (c) del tubo en el acoplamiento debe estar entre 0.04λ a 0.05λ; luego, su diámetro debe ser 1/3 o 1/2 del diámetro del conductor del dipolo, con una separación respecto al dipolo (b) aproximadamente igual a 0.007λ.

## Universidad Nacional Mayor de San Marcos

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

Mg. Hansel Martínez Odiaga | Página N°35 | 2026—I

4.2.— Dispositivos de Balanceamiento (Baluns)

Son utilizados para conectar un sistema balanceado (dipolo) a uno desbalanceado (conductor coaxial), comúnmente son denominados Baluns. Un conductor coaxial conectado a un dipolo produce cierto desbalanceamiento, esto se debe a que, a pesar de estar el conductor coaxial inicialmente balanceado (la corriente en los conductores internos/externos son iguales con signos opuestos), cuando la señal llega hasta el dipolo (vía coaxial) la corriente fluye a través de la superficie externa del conductor externo, lo que resulta en una corriente total a lo largo de la línea de transmisión que produce el desbalance en el dipolo—línea, como también produce una radiación que afecta al diagrama de radiación del dipolo.

Figura N°24_ Corte Longitudinal de Dipolo Alimentado con Conductor Coaxial

Figura N°25_ Baluns del tipo (a) Bazuka, (b) Trombón, (c) Núcleo de Ferrita

## Universidad Nacional Mayor de San Marcos

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

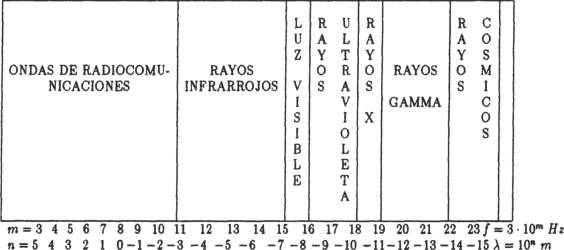
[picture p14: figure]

Mg. Hansel Martínez Odiaga | Página N°36 | 2026—I

5.— Propagación de Ondas VHF

5.1.— Espectro Electromagnético

Dado que el periodo es el inverso de la frecuencia, se tiene que los parámetros λ, v, f se encuentran relacionados mediante:

Como la velocidad de propagación depende de características electromagnéticas del medio, la longitud de onda varía de un medio a otro. En el espacio libre, la velocidad es la de la luz: v = 3×10⁸ m/s.

En la naturaleza, existe amplio espectro de ondas electromagnéticas que se extiende desde frecuencias demasiado bajas (longitudes de ondas grandes) hasta frecuencias demasiado altas (longitudes de onda inimaginablemente pequeñas). Esta banda total de frecuencias de longitudes de ondas de las ondas electromagnéticas se denomina: Espectro Electromagnético o Espectro de Frecuencias.

Figura N°26_ Espectro Electromagnético

## Universidad Nacional Mayor de San Marcos

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

Mg. Hansel Martínez Odiaga | Página N°37 | 2026—I

La parte del Espectro Electromagnético correspondiente a las ondas de radiocomunicaciones cubre el rango de 3 kHz hasta 300 GHz en bandas. Este recibe el nombre de Espectro Radioeléctrico.

Figura N°27_ Espectro Radioeléctrico

## Universidad Nacional Mayor de San Marcos

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

Mg. Hansel Martínez Odiaga | Página N°38 | 2026—I

5.2.— Principio de Radiación de Antenas

Las antenas son dispositivos usados para la emisión o recepción de ondas electromagnéticas. Todas las antenas funcionan de manera similar: al conectar una fuente de corriente alterna en los terminales de la antena aparece una distribución de tensión/corriente a lo largo de ella, las cuales varían de acuerdo a las dimensiones o tipos de antena. La distribución de tensión/corriente de una antena dipolo de media onda se encuentra dada, donde se puede apreciar que los extremos de la antena son puntos de máxima tensión pero de mínima corriente. La diferencia de potencial entre los conductores de la antena crea un campo eléctrico, el cual es ortogonal al campo magnético creado por la corriente que circula en ella.

Figura N°28_ Distribución de Tensión/Corriente en Antena Dipolo Media Onda

Figura N°29_ Campos Electromagnéticos de Antena Dipolo Media Onda

## Universidad Nacional Mayor de San Marcos

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

Mg. Hansel Martínez Odiaga | Página N°39 | 2026—I

Los campos electromagnéticos creados por la antena alcanzarán valores mínimos o máximos, lo que depende de la magnitud de la corriente. Se muestra una antena dipolo de media onda con la corriente de su fuente de alimentación. Al conectar dicha fuente, en el instante t = 0, la corriente en la antena es nula (no se crea ningún campo). Al ir aumentando la corriente hasta alcanzar su valor máximo, en el tiempo t = T/4, las líneas de campo eléctrico crecen, se cierran pero se alejan de la antena, quedando libres en t = T/2. Durante el siguiente semiciclo se ha de formar un nuevo paquete de líneas de campo eléctrico, el cual es igual al previo pero en sentido contrario, por lo tanto, estas empujan las líneas que se habían desprendido antes de la antena, haciendo que se desplacen en una dirección determinada.

Figura N°30_ (a) Corriente de Alimentación en Antena Dipolo de Media Onda
(b) t = 0, (c) t = T/8, (d) t = T/4, (e) t = 3T/8, (f) t = T/2, (g) t = 3T/4

Entonces, el proceso que se repite es la causa de la formación/propagación de ondas electromagnéticas, dado que el campo magnético generado por la corriente que circula por la antena se comporta de la misma forma que el campo eléctrico inducido en la antena.

## Universidad Nacional Mayor de San Marcos

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

Mg. Hansel Martínez Odiaga | Página N°40 | 2026—I

5.3.— Propagación, Ruido e Interferencias Ambientales

Las ondas electromagnéticas radiadas por una antena tienden a viajar en línea recta. Pero existen unos factores que curvan las ondas haciendo posible las radiocomunicaciones actuales. Dependiendo de la frecuencia usada, la polarización de la onda, las características radioeléctricas del terreno sobre el cual se propaga la onda, la longitud del trayecto, la topografía del terreno, las condiciones troposféricas e ionosféricas, la propagación de las ondas electromagnéticas puede clasificarse en una propagación por onda superficial, en propagación por onda ionosférica o en propagación por onda troposférica.

Figura N°31_ Modos de Propagación de Ondas Electromagnéticas

## Universidad Nacional Mayor de San Marcos

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

Mg. Hansel Martínez Odiaga | Página N°41 | 2026—I

En Propagación por Onda Superficial o Terrestre la señal tiende a seguir toda superficie terrestre, alcanzando grandes distancias. Esta propagación ocurre en la polarización vertical. La propagación por onda superficial es ideal en bajas frecuencias, reduciendo su eficiencia mientras aumenta la frecuencia.

La Propagación por Onda Ionosférica utiliza capas ionizadas de la atmósfera superior para reflejar hacia la tierra las ondas electromagnéticas. Existen cuatro capas de diferente ionización: D, E, F1, F2. Estas capas varían en altitud o espesor dependiendo de la hora del día, mes o año.

La Propagación por Onda Troposférica ocurre en la troposfera pero puede darse como a) Onda Directa/Reflejada, b) Onda Difractada, c) Onda de Dispersión.

La señal radiada por una antena transmisora, antes de llegar al equipo receptor, sufre atenuaciones a lo largo de la trayectoria seguida; además, es contaminada por ruido e interferencias ambientales. El nivel de señal necesario para comunicación satisfactoria está determinado por el ruido de fondo captado por la antena, procedente de las fuentes cósmicas, atmosféricas o terrestres. En el diseño de un sistema de comunicaciones, la intensidad de ruido es un factor crucial para determinar la potencia del transmisor o determinar la máxima distancia que se puede cubrir con un transmisor de potencia dada. Los ruidos que predominan en un sistema de comunicación son: estáticos o atmosféricos, cósmicos o galácticos, ruidos producidos por el hombre. Estos ruidos no afectan la señal todos al mismo tiempo; depende de la frecuencia utilizada el ruido que será predominante.

El Ruido Atmosférico tiene su origen en ciertas tormentas eléctricas o en otros disturbios eléctricos naturales que se producen en la atmósfera. Se caracteriza por ser impulsivo, su energía se distribuye en una amplia banda de frecuencias útiles, predominando hasta los 30 MHz. A medida que aumenta la frecuencia, el nivel de ruido atmosférico se reduce; ergo, para frecuencias bastante altas, su influencia es casi nula, entrando a prevalecer la influencia del ruido cósmico o galáctico.

Las fuentes de Ruido Cósmico o Galáctico son la Vía Láctea, las galaxias o el Sol, aunque existen otras fuentes puntuales de alta intensidad de ruido. El ruido proveniente del Sol se encuentra formado por una radiación aproximadamente constante que, en algunas frecuencias, es considerablemente más intensa. Además, existen ruidos adicionales provenientes de las manchas, llamaradas, etc. Estos ruidos pueden ser de alta intensidad, predominando hasta aproximadamente 1 GHz. Para ciertas frecuencias que superen los 1 GHz, los componentes absorbentes de la atmósfera, como el vapor de agua, oxígeno e hidrometeoros, también actúan como fuentes de ruido.

Los Ruidos Producidos por el Hombre son artificiales porque provienen de aparatos eléctricos que usan conmutación (motores o generadores de CC), contactos vibrantes, arcos o cualquier mecanismo que dé lugar a chispas eléctricas, dado que estos producen la radiación de ondas amortiguadas en una amplia gama de frecuencias. Este tipo de ruido predomina en las zonas industriales.

## Universidad Nacional Mayor de San Marcos

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

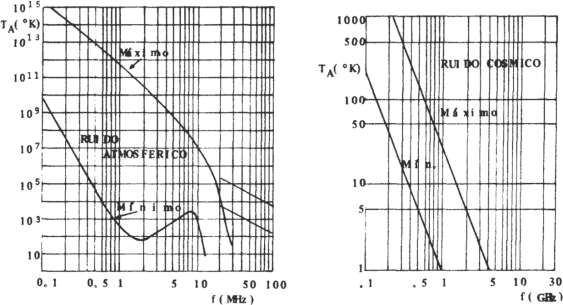
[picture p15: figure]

Mg. Hansel Martínez Odiaga | Página N°42 | 2026—I

Figura N°32_ Temperatura de Ruido en Diferentes Frecuencias

5.4.— Efecto de la Tierra sobre el Diagrama de Radiación

Dependiendo de la distancia que exista entre una antena con la superficie terrestre, o una superficie conductora, los parámetros característicos de las antenas, estudiados en el espacio libre, pueden sufrir modificaciones. Luego, se muestran dipolos ideales con diferente polarización a una distancia hT de la superficie terrestre. Si el dipolo vertical se encuentra en espacio libre, las cargas/corrientes que circulan en él producen un campo electromagnético lejano de componentes Eθ, Hφ. La presencia de la tierra o de cualquier otra superficie conductora hace que el campo electromagnético radiado por la antena, al incidir en la superficie, induzca cargas/corrientes con magnitudes, fases que dependen de la frecuencia, conductividad o permitividad de dicha superficie. De este modo, el campo radiado por una antena en presencia de tierra está formado por el campo producido por las cargas/corrientes de la antena más el campo producido por las cargas/corrientes inducidas en el PEC. En consecuencia, para el cálculo total del campo radiado por el dipolo, es conveniente utilizar la Teoría de Imágenes, que consiste en realizar una sustitución de la superficie cargada por cargas/corriente colocadas a una distancia apropiada.

## Universidad Nacional Mayor de San Marcos

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

Mg. Hansel Martínez Odiaga | Página N°43 | 2026—I

Figura N°33_ Dipolos Ideales en Presencia de PEC

Figura N°34_ Campos Radiados por Dipolos Ideales en Presencia de PEC

## Universidad Nacional Mayor de San Marcos

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

Mg. Hansel Martínez Odiaga | Página N°44 | 2026—I

En conclusión, el diagrama de radiación en el plano vertical varía con la frecuencia, con la posición de la antena con respecto a la tierra, con la distancia d de la antena al punto donde se determina el campo; mientras que el diagrama de radiación en el plano horizontal permanece invariable. En la figura, se nos muestra cómo varía el diagrama de radiación con la distancia de la antena a la superficie terrestre.

Figura N°35_ (a), (b) Diagramas de Radiación de Dipolo Vertical en Presencia de PEC (c), (d) Diagramas de Radiación de Dipolo Horizontal en Presencia de PEC

## Universidad Nacional Mayor de San Marcos

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

Mg. Hansel Martínez Odiaga | Página N°45 | 2026—I

PROCEDIMIENTO DE DISEÑO DEL TRANSMISOR FM

1.— Definición del Sistema

Enfoque: Establecer los objetivos del sistema.

Objetivo Principal: Diseñar e implementar un sistema electrónico en lazo abierto que logre modular de manera lineal una señal de información (audio) sobre una onda portadora de alta frecuencia (RF).

Figura N°36_ Objetivo Principal: Modulación FM

## Universidad Nacional Mayor de San Marcos

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

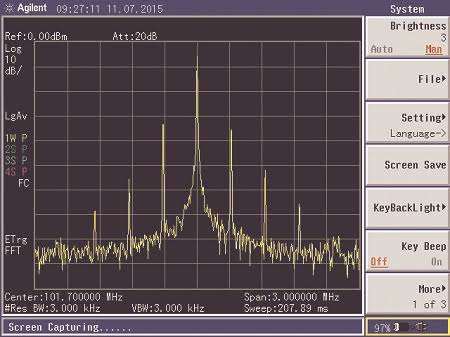
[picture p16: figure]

Mg. Hansel Martínez Odiaga | Página N°46 | 2026—I

Meta de Estabilidad: Lograr que la frecuencia central de oscilación se mantenga fija en el canal que sea seleccionado, minimizando la deriva de frecuencia provocada por perturbaciones externas.

Figura N°37_ Meta de Estabilidad: Frecuencia de Portadora Estable

Propósito de Transmisión: Irradiar la señal modulada al espacio libre de forma eficiente dentro de cierto radio de cobertura controlado (corto alcance), asegurando una óptima relación señal/ruido para que pueda ser sintonizada mediante un Receptor Comercial o mediante un Analizador de Espectros.

Figura N°38_ Propósito de Transmisión: Sintonización en Analizador de Espectros

## Universidad Nacional Mayor de San Marcos

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

Mg. Hansel Martínez Odiaga | Página N°47 | 2026—I

2.— Requerimientos del Sistema

Enfoque: Identificar las variables que se desean controlar con sus especificaciones.

Variable Controlada (Frecuencia de Portadora): La frecuencia instantánea de la señal de salida. Su especificación dicta que debe ubicarse en un canal dentro de la banda de FM (88 MHz a 108 MHz).

Figura N°39_ Variable Controlada: Frecuencia de Portadora

Variable de Entrada (Señal Moduladora): Amplitud, frecuencia de la señal de audio proveniente de un micrófono o un teléfono celular. Esta variable determina la deriva de la frecuencia controlada.

Figura N°40_ Variable de Entrada: Señal Moduladora de Audio

## Universidad Nacional Mayor de San Marcos

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

Mg. Hansel Martínez Odiaga | Página N°48 | 2026—I

Límites de la Variable del Actuador (Δf): La desviación máxima de frecuencia no debe superar los ±75 kHz para cumplir con el estándar comercial, evitando alguna invasión en los canales adyacentes.

Figura N°41_ Límites de la Variable del Actuador: Desviación de Frecuencia Controlada

Variable de Potencia: La amplitud o potencia de señal de RF entregada a la carga, la cual debe operar bajo condiciones estrictas de baja potencia para el análisis de resultados obtenidos en las mediciones.

Figura N°42_ Variable de Potencia: Control de Potencia de Señal RF

## Universidad Nacional Mayor de San Marcos

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

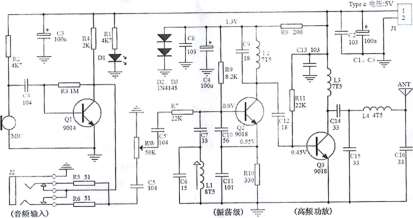
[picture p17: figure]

Mg. Hansel Martínez Odiaga | Página N°49 | 2026—I

3.— Condiciones del Sistema

Enfoque: Definición de restricciones físicas que acotan las iteraciones del diseño.

Restricción de Potencia: El sistema está condicionado a trabajar con potencia de salida de máximo 100 mW. Esto limita el diseño al uso exclusivo de transistores de baja potencia, pequeña señal para RF (por ejemplo, la familia 2N2222A, BF494 o similares), prohibiendo transistores de potencia medianos o altos que violen la cobertura estipulada de 10 a 50 metros.

Figura N°43_ Restricción de Potencia: Familias de Transistores de Baja Potencia

Condición de Discretización: Se restringe el uso de módulos integrados que simplifiquen de manera directa la modulación FM. El lazo de control debe construirse mediante unos componentes discretos.

Figura N°44_ Condición de Discretización: Transmisor FM con Componentes Discretos

## Universidad Nacional Mayor de San Marcos

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

Mg. Hansel Martínez Odiaga | Página N°50 | 2026—I

Condición de Estabilidad Física: Para mitigar el ruido, asegurando que nuestras especificaciones no se degraden por los elementos parásitos, se condiciona la implementación final a una tarjeta de circuito impreso (PCB), descartando el uso definitivo de protoboardsen la fase experimental fija de modelado.

Figura N°45_ Condición de Estabilidad Física: Transmisor FM en Diseño PCB

Condición de Alimentación: El circuito debe estar restringido a operar bajo un voltaje fijo nominal, el cual debe ser seleccionado estrictamente entre las opciones de 5 V, 9 V o 12 V de corriente continua.

Figura N°46_ Condición de Alimentación: Voltaje Fijo Nominal Especificado

## Universidad Nacional Mayor de San Marcos

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

Mg. Hansel Martínez Odiaga | Página N°51 | 2026—I

4.— Diagrama de Bloques del Sistema

Figura N°47_ Transmisor FM: Diagrama de Bloques

Bloque N°01: Fuente de Audio + Preamplificador de Audio
Recibe la señal débil de audio, elevando su amplitud para que sea capaz de excitar la siguiente etapa.

Bloque N°02: Oscilador RF + Modulador FM
Funciona como VCO. La combinación de red LC con un elemento de inductancia variable modifica la frecuencia de oscilación de RF al compás del voltaje de audio de la etapa previa.

Bloque N°03: Etapa Buffer + Amplificador RF
El buffer separa eléctricamente al oscilador de cambios de carga externos para que no sufra variaciones de frecuencia. Posteriormente, el amplificador eleva la señal RF hasta el umbral seguro permitido.

Bloque N°04: Filtro de Salida + Antena Transmisora
El filtro LC atenúa armónicos secundarios generados por la amplificación no lineal, entregando una señal pura a la antena (monopolo o dipolo) para su radiación eficiente.

## Universidad Nacional Mayor de San Marcos

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

Mg. Hansel Martínez Odiaga | Página N°52 | 2026—I

5.— Costo de Implementación del Sistema

— Transistor 9014 (S/. 0.50 c/u): Hemos seleccionado este componente porque es un BJT NPN de ultra bajo ruido con una alta ganancia (hFE), lo que permite amplificar los mV del micrófono electret sin meterle ruido térmico al lazo analógico de audio antes de la modulación FM.

Figura N°48_ Costo de Implementación: Transistor 9014

## Universidad Nacional Mayor de San Marcos

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

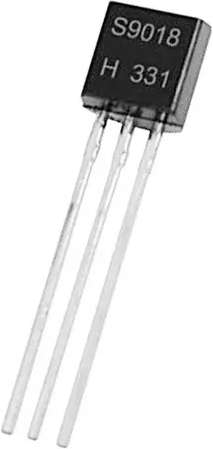
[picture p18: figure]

Mg. Hansel Martínez Odiaga | Página N°53 | 2026—I

— Transistor 9018 (S/. 1.00 c/u): Hemos seleccionado este componente dado que es un transistor de alta frecuencia por excelencia para proyectos universitarios; su frecuencia de transición (fT) de hasta 1.1 GHz asegura que tanto la etapa del oscilador local como buffer/amplificador trabajen en la banda FM de 88—108 MHz sin colgarse ni perder ganancia.

Figura N°49_ Costo de Implementación: Transistor 9018

## Universidad Nacional Mayor de San Marcos

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

Mg. Hansel Martínez Odiaga | Página N°54 | 2026—I

— Jack Hembra 3.5mm + Micrófono Electret (S/. 3.00): Hemos seleccionado estos componentes porque nos dan versatilidad de acoplamiento exigida en los requerimientos, permitiendo conmutar la entrada de control entre la señal de un celular (música) o voz en vivo mediante el micrófono.

Figura N°50_ Costo de Implementación: Jack Hembra 3.5mm

## Universidad Nacional Mayor de San Marcos

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

Mg. Hansel Martínez Odiaga | Página N°55 | 2026—I

Figura N°51_ Costo de Implementación: Micrófono Electret

## Universidad Nacional Mayor de San Marcos

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

Mg. Hansel Martínez Odiaga | Página N°56 | 2026—I

— Bobina blindada/ajustable 7 Vueltas (S/. 2.00): Hemos seleccionado este componente porque al tener un núcleo de ferrita ajustable, nos permite calibrar de manera manual/precisa la inductancia de tanque resonante, logrando sintonizar el transmisor exactamente en un canal libre del espectro FM.

Figura N°52_ Costo de Implementación: Bobina Blindada/Ajustable 7 Vueltas

## Universidad Nacional Mayor de San Marcos

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

Mg. Hansel Martínez Odiaga | Página N°57 | 2026—I

— Lote de Condensadores Cerámicos (S/. 3.00): Hemos seleccionado estos componentes porque, al presentar valores en el orden de los picofaradios (pF), son los únicos capaces de fijar una frecuencia de oscilación VHF; además, el circuito aprovecha eficazmente una capacitancia interna base—colector de Q2 para simular el comportamiento de un diodo varactor, logrando la modulación FM.

Figura N°53_ Costo de Implementación: Condensadores Cerámicos 102P

## Universidad Nacional Mayor de San Marcos

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

Mg. Hansel Martínez Odiaga | Página N°58 | 2026—I

Figura N°54_ Costo de Implementación: Condensadores Cerámicos 104P

## Universidad Nacional Mayor de San Marcos

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

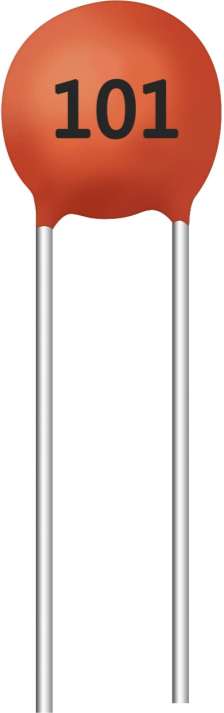
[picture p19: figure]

Mg. Hansel Martínez Odiaga | Página N°59 | 2026—I

Figura N°55_ Costo de Implementación: Condensadores Cerámicos 101P

## Universidad Nacional Mayor de San Marcos

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

Mg. Hansel Martínez Odiaga | Página N°60 | 2026—I

Figura N°56_ Costo de Implementación: Condensadores Cerámicos 30P

## Universidad Nacional Mayor de San Marcos

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

Mg. Hansel Martínez Odiaga | Página N°61 | 2026—I

Figura N°57_ Costo de Implementación: Condensadores Cerámicos 68P

## Universidad Nacional Mayor de San Marcos

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

Mg. Hansel Martínez Odiaga | Página N°62 | 2026—I

Figura N°58_ Costo de Implementación: Condensadores Cerámicos 15P

## Universidad Nacional Mayor de San Marcos

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

Mg. Hansel Martínez Odiaga | Página N°63 | 2026—I

— Lote Resistencias, Capacitor Electrolítico (S/. 4.00): Hemos seleccionado estos componentes porque se encargan de establecer los puntos de operación estáticos (polarización) para los transistores, limpiando el rizado de alta frecuencia (RF) que pueda venir de la fuente de alimentación CC.

Figura N°59_ Costo de Implementación: Resistencia 100 Ω

## Universidad Nacional Mayor de San Marcos

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

Mg. Hansel Martínez Odiaga | Página N°64 | 2026—I

Figura N°60_ Costo de Implementación: Resistencia 470 Ω

## Universidad Nacional Mayor de San Marcos

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

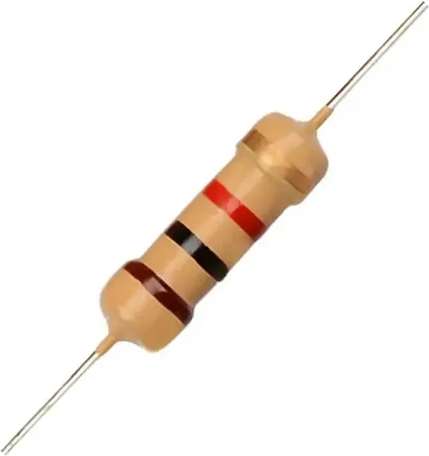
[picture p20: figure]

Mg. Hansel Martínez Odiaga | Página N°65 | 2026—I

Figura N°61_ Costo de Implementación: Resistencia 10 kΩ

## Universidad Nacional Mayor de San Marcos

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

Mg. Hansel Martínez Odiaga | Página N°66 | 2026—I

Figura N°62_ Costo de Implementación: Resistencia 22 kΩ

## Universidad Nacional Mayor de San Marcos

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

Mg. Hansel Martínez Odiaga | Página N°67 | 2026—I

Figura N°63_ Costo de Implementación: Resistencia 47 kΩ

## Universidad Nacional Mayor de San Marcos

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

Mg. Hansel Martínez Odiaga | Página N°68 | 2026—I

Figura N°64_ Costo de Implementación: Resistencia 100 kΩ

## Universidad Nacional Mayor de San Marcos

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

Mg. Hansel Martínez Odiaga | Página N°69 | 2026—I

Figura N°65_ Costo de Implementación: Capacitor Electrolítico 47 μF

## Universidad Nacional Mayor de San Marcos

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

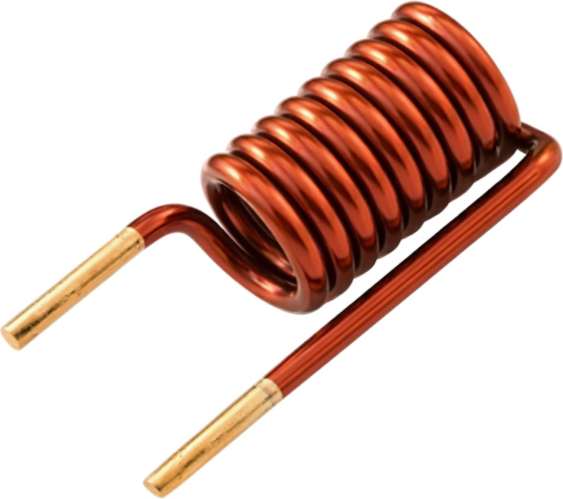
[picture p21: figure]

Mg. Hansel Martínez Odiaga | Página N°70 | 2026—I

— Filtro de Salida, Inductores (S/. 1.50): Hemos seleccionado estos componentes porque forman red de filtrado pasivo en la configuración π, indispensable para atenuar los armónicos superiores que genera el amplificador Q3, asegurando que la potencia máxima se concentre únicamente en portadora fundamental, nunca superando la condicional de los 100 mW.

Figura N°66_ Costo de Implementación: Inductancia 8T

## Universidad Nacional Mayor de San Marcos

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

Mg. Hansel Martínez Odiaga | Página N°71 | 2026—I

Figura N°67_ Costo de Implementación: Inductancia 5T

## Universidad Nacional Mayor de San Marcos

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

Mg. Hansel Martínez Odiaga | Página N°72 | 2026—I

Figura N°68_ Costo de Implementación: Antena Dipolo de Media Onda

## Universidad Nacional Mayor de San Marcos

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

Mg. Hansel Martínez Odiaga | Página N°73 | 2026—I

— Placa de Fenólica + Cloruro Férrico (S/. 5.00): Hemos seleccionado estos componentes porque armar un circuito de 100 MHz en protoboard es una ineficiencia electrónica debido a las capacitancias parásitas; el PCB nos garantiza una alta estabilidad del sistema requerida en la modulación FM.

Figura N°69_ Costo de Implementación: Placa de Fenólica

## Universidad Nacional Mayor de San Marcos

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

Mg. Hansel Martínez Odiaga | Página N°74 | 2026—I

Figura N°70_ Costo de Implementación: Cloruro Férrico

## Universidad Nacional Mayor de San Marcos

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

Mg. Hansel Martínez Odiaga | Página N°75 | 2026—I

CÁLCULOS DE DISEÑO DEL TRANSMISOR FM

Bloque N°01: Fuente de Audio + Preamplificador de Audio

— Diagrama Esquemático

Figura N°71_ Bloque N°01: Diagrama Esquemático

— Componentes Electrónicos

Entrada AC (V1): 0.5×10⁻³

sin(2πt)
Entrada DC (V2): 9 V
Resistencias (R1, R2, R3, R4, R5): 10 kΩ, 100 kΩ, 10 kΩ, 5 kΩ, 22 kΩ Capacitores Cerámicos (C1, C2): 0.1 μF, 0.1 μF
Transistor BJT (Q1): S9014

## Universidad Nacional Mayor de San Marcos

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

Mg. Hansel Martínez Odiaga | Página N°76 | 2026—I

— Parámetros del Transistor Q1

1.— Parámetros de Corriente Directa

Corriente de Saturación de Transporte: IS [A] = 2.68×10⁻¹⁴ Ganancia de Corriente Máxima en Directo: βF = 320
Factor de Idealidad de Corriente de Colector en Directo: NF = 1.0
Voltaje de Early en Directo: VAF [V] = 80
Corriente de Esquina en Caída de Ganancia en Directo: IKF [A] = 0.14 Corriente de Saturación de Fuga de Unión Base—Emisor: ISE [A] = 1.20×10⁻¹⁴ Factor de Idealidad de Fuga de Unión Base—Emisor: NE = 1.5
Ganancia de Corriente Máxima en Inverso: βR = 4
Factor de Idealidad de Corriente de Emisor en Inverso: NR = 1.0
Voltaje de Early en Inverso: VAR [V] = 20
Corriente de Esquina en Caída de Ganancia en Inverso: IKR [A] = 0.01 Corriente de Saturación de Fuga de Unión Base—Colector: ISC [A] = 0 Factor de Idealidad de Fuga de Unión Base—Colector: NC = 2.0

2.— Parámetros de Resistencias Parásitas

Resistencia de Base Máxima: RB [Ω] = 10
Corriente de Caída de RBASE entre RB—RBM: IRB [A] = 0.1 Resistencia de Base Mínima: RBM [Ω] = 1
Resistencia Óhmica de Emisor: RE [Ω] = 0.4
Resistencia Óhmica de Colector: RC [Ω] = 0.8

3.— Parámetros de Capacitancias Parásitas

Capacitancia de Depleción de Unión Base—Emisor a Voltaje Cero: CJE [F] = 2.2×10⁻¹¹ Potencial de Contacto de Unión Base—Emisor: VJE [V] = 0.75
Factor Exponencial de Unión Base—Emisor: MJE = 0.33
Capacitancia de Depleción de Unión Base—Colector a Voltaje Cero: CJC [F] = 7.5×10⁻¹² Potencial de Contacto de Unión Base—Colector: VJC [V] = 0.75
Factor Exponencial de Unión Base—Colector: MJC = 0.33

4.— Parámetros de Tiempo Transitorio

Tiempo de Tránsito Ideal de Carga de Base en Directo: TF [s] = 5×10⁻¹⁰ Tiempo de Tránsito Ideal de Carga de Base en Inverso: TR [s] = 1×10⁻¹⁸

## Universidad Nacional Mayor de San Marcos

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

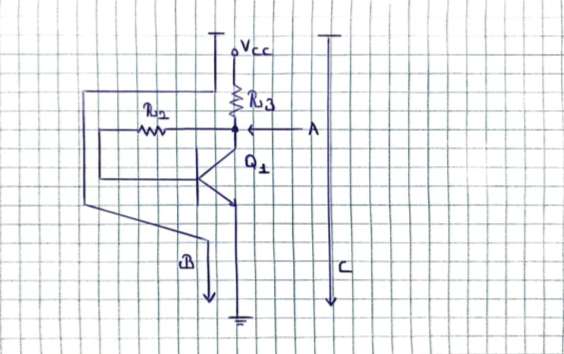
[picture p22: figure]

Mg. Hansel Martínez Odiaga | Página N°77 | 2026—I

5.— Parámetros de Temperatura/Material

Brecha de Energía (Bandgap) del Silicio: EG [eV] = 1.11
Exponente de Temperatura en Corriente de Saturación: XTI = 3

6.— Parámetros de Especificaciones del Fabricante

Voltaje Máximo de Colector—Emisor en Base Abierta: VCEO [V] = 45 Corriente Máxima de Colector Recomendada: ICRATING [A] = 0.1 Fabricante del Componente: Fairchild

— Análisis DC

Figura N°72_ Bloque N°01: Circuito Equivalente DC

De la Ley de Corrientes de Kirchhoff en el Nodo A:

## Universidad Nacional Mayor de San Marcos

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

Mg. Hansel Martínez Odiaga | Página N°78 | 2026—I

ICC = IR2 + IC

ICC = IR2 + βIR2

ICC = (β + 1)IR2

De la Ley de Voltajes de Kirchhoff en la Malla B:

VCC − VR3 − VR2 − VBE = 0

VR2 = VCC − VR3 − VBE

VR2 = VCC − VBE − ICCR3

IR2R2 = VCC − VBE − ICCR3

IR2R2 = VCC − VBE − (β + 1)IR2R3

IR2 | = IB | = [VCC − VBE]/[R2 + (β + 1)R3]

De la Ley de Voltajes de Kirchhoff en la Malla C:

| | VCC − VR3 − VCE = 0
| | VCE = VCC − VR3
| | VCE = VCC − IR3R3
VCE | = VCC − (β + 1)IR2R3

De las ecuaciones obtenidas:

## Universidad Nacional Mayor de San Marcos

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

Mg. Hansel Martínez Odiaga | Página N°79 | 2026—I
IB | = 2.5 μA
IC | = 0.8 mA
VCE | = 0.975 V

Q = (VCE, IC) = (0.975, 0.8)

De la Resistencia Térmica a Temperatura Constante (VT ∼ 25 mV):

re = VT/ICC

re = VT/(IR2 + IC)

re = 31.15 Ω

De la Resistencia Intrínseca de Salida:

ro | = VAF/IC
ro | = 100 kΩ

— Análisis AC

Figura N°73_ Bloque N°01: Circuito Equivalente AC

Del análisis en la Red de Entrada:

## Universidad Nacional Mayor de San Marcos

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

Mg. Hansel Martínez Odiaga | Página N°80 | 2026—I

Zi ∼ βre

Zi ∼ 9.96 kΩ

Del análisis en la Red de Salida:

Zo | = R3 || ro
Zo | = 9.09 kΩ

De la Ley de Ohm en la Red de Entrada:

Vi = βIBre

De la Ley de Ohm en la Red de Salida:

Vo = −βIB(R3 || ro)

Del análisis de Ganancia de Tensión:

Av = Vo/Vi

Av = [−βIB(R3 || ro)]/[βIBre]

Av = −(R3 || ro)/re

Av = −291.81

— Análisis de Respuesta en Frecuencia

## Universidad Nacional Mayor de San Marcos

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

Mg. Hansel Martínez Odiaga | Página N°81 | 2026—I

Figura N°74_ Bloque N°01: Circuito Equivalente de Respuesta en Frecuencia

Del análisis en la Red de Corte Inferior:

fCL | = 1/[2π(R1 || βre)C1]
fCL | = 0.318 kHz

Del análisis de Capacitancia Miller:

CM | = CJE + CJC(1 − Av)
CM | = 2.21 nF

Del análisis en la Red de Corte Superior:

fCH | = 1/[2π[R1 || βre || R2/(1 − Av)](CM)]
fCH | = 15.193 kHz

## Universidad Nacional Mayor de San Marcos

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

Mg. Hansel Martínez Odiaga | Página N°82 | 2026—I

Figura N°75_ Bloque N°01: Diagrama Asintótico de Bode

## Universidad Nacional Mayor de San Marcos

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

Mg. Hansel Martínez Odiaga | Página N°83 | 2026—I

Bloque N°02: Oscilador RF + Modulador FM

— Diagrama Esquemático

Figura N°76_ Bloque N°02: Diagrama Esquemático

— Componentes Electrónicos

Resistencias (R5, R7, R8, R9): 10 kΩ, 47 kΩ, 100 Ω, 470 Ω
Capacitores Cerámicos (C3, C4, C5, C6, C7, C8, C9, C10): 47 μF, 0.1 μF, 30 pF, 15 pF, 68 pF, 0.1 nF, 1 nF, 0.1 nF
Diodo (D1): Light—Emitting Diode
Bobinas (L1, L2): 100 nH, 35 nH
Transistor BJT (Q2): S9018

## Universidad Nacional Mayor de San Marcos

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

Mg. Hansel Martínez Odiaga | Página N°84 | 2026—I

— Parámetros del Transistor Q2

1.— Parámetros de Corriente Directa

Corriente de Saturación de Transporte: IS [A] = 3×10⁻¹⁵
Ganancia de Corriente Máxima en Directo: βF = 102
Voltaje de Early en Directo: VAF [V] = 75
Corriente de Esquina en Caída de Ganancia en Directo: IKF [A] = 0.25 Corriente de Saturación de Fuga de Unión Base—Emisor: ISE [A] = 0.8×10⁻¹² Factor de Idealidad de Fuga de Unión Base—Emisor: NE = 2
Ganancia de Corriente Máxima en Inverso: βR = 0.3
Corriente de Esquina en Caída de Ganancia en Inverso: IKR [A] = 0.01 Corriente de Saturación de Fuga de Unión Base—Colector: ISC [A] = 0.8×10⁻¹² Factor de Idealidad de Fuga de Unión Base—Colector: NC = 2

2.— Parámetros de Resistencias Parásitas

Resistencia Óhmica de Base: RB [Ω] = 60
Resistencia Óhmica de Colector: RC [Ω] = 3.5

3.— Parámetros de Capacitancias Parásitas

Capacitancia de Depleción de Unión Base—Colector a Voltaje Cero: CJC [F] = 1.8×10⁻¹² Potencial de Contacto de Unión Base—Colector: VJC [V] = 0.8
Factor Exponencial de Unión Base—Colector: MJC = 0.15
Fracción de Capacitancia Base—Colector en Nodo de Base: XCJC = 0.1
Capacitancia de Depleción de Unión Base—Emisor a Voltaje Cero: CJE [F] = 1.5×10⁻¹² Potencial de Contacto de Unión Base—Emisor: VJE [V] = 0.8
Factor Exponencial de Unión Base—Emisor: MJE = 0.5
Coeficiente de Capacitancia de Unión en Directa: FC = 0.5

4.— Parámetros de Tiempo Transitorio

Tiempo de Tránsito Ideal de Carga de Base en Directo: TF [s] = 0.11×10⁻⁹ Tiempo de Tránsito Ideal de Carga de Base en Inverso: TR [s] = 2×10⁻⁹ Parámetro de Corriente en Tiempo de Tránsito Directo: ITF [A] = 13×10⁻³ Parámetro de Voltaje en Tiempo de Tránsito Directo: VTF [V] = 1.7 Coeficiente Exponencial en Tiempo de Tránsito Directo: XTF [V] = 3

## Universidad Nacional Mayor de San Marcos

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

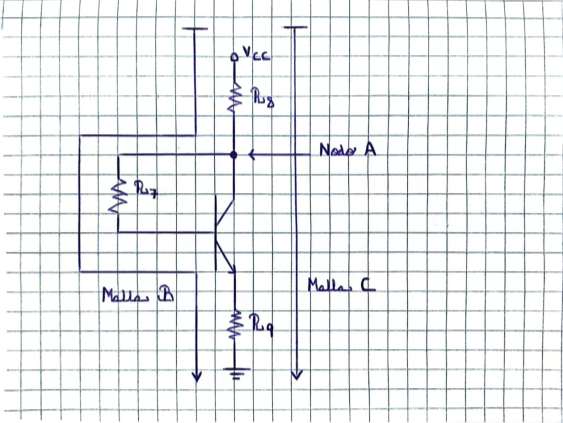
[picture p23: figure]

Mg. Hansel Martínez Odiaga | Página N°85 | 2026—I

5.— Parámetros de Temperatura

Exponente de Temperatura en Corriente de Saturación: XTI = 3 Exponente de Temperatura en Ganancia de Corriente: XTB = 1.5

6.— Parámetros de Especificaciones del Fabricante

Voltaje Máximo de Colector—Emisor en Base Abierta: VCEO [V] = 15 Corriente Máxima de Colector Recomendada: ICRATING [A] = 0.05 Fabricante del Componente: Fairchild

— Análisis DC

Figura N°77_ Bloque N°02: Circuito Equivalente DC

## Universidad Nacional Mayor de San Marcos

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

Mg. Hansel Martínez Odiaga | Página N°86 | 2026—I

De la Ley de Corrientes de Kirchhoff en el Nodo A:

ICC = IR7 + IC

ICC = IR7 + βIR7

ICC = (β + 1)IR7

De la Ley de Voltajes de Kirchhoff en la Malla B:

VCC − VR8 − VR7 − VBE − VR9 = 0

VCC − ICCR8 − IR7R7 − VBE − ICCR9 = 0

VCC − (β + 1)IR7R8 − IR7R7 − VBE − (β + 1)IR7R9 = 0

IR7 | = IB | = [VCC − VBE]/[R7 + ((β + 1))(R8 + R9)]

De la Ley de Voltajes de Kirchhoff en la Malla C:

| | VCC − VR8 − VCE − VR9 = 0
| | VCE = VCC − VR8 − VR9
| | VCE = VCC − ICCR8 − ICCR9

VCE = VCC − (β + 1)IR7R8 − (β + 1)IR7R9

VCE = VCC − (β + 1)(R8 + R9)IR7

De las ecuaciones obtenidas:

IB | = 77.57 μA
IC | = 7.91 mA
VCE | = 4.45 V

Q = (VCE, IC) = (4.45, 7.91)

## Universidad Nacional Mayor de San Marcos

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

Mg. Hansel Martínez Odiaga | Página N°87 | 2026—I

De la Resistencia Térmica a Temperatura Constante (VT ∼ 25 mV):

re = VT/ICC

re = VT/(IR7 + IC)

re = 3.13 Ω

De la Resistencia Intrínseca de Salida:

ro | = VAF/IC
ro | = 9.48 kΩ

— Análisis AC

Figura N°78_ Bloque N°02: Circuito Equivalente AC

Del análisis en la Red de Entrada:

## Universidad Nacional Mayor de San Marcos

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

Mg. Hansel Martínez Odiaga | Página N°88 | 2026—I

Zi = R7 || [βre + (β + 1)R9]

Zi = 23.92 kΩ

Del análisis en la Red de Salida:

Zo | = re || ro
Zo | = 3.12 Ω

De la Ley de Ohm en la Red de Entrada:

Vi = βIBre + (β + 1)IBR9

De la Ley de Ohm en la Red de Salida:

Vo = βIBR9

Del análisis de Ganancia de Tensión:

Av = Vo/Vi

Av = βR9/[βre + (β + 1)R9]

Av = 0.983

Del análisis en la Red de Sintonización Capacitiva:

CEQ = (C5 || C7) + C6

CEQ = 35.8 pF

Del análisis en la Frecuencia de Oscilación:

## Universidad Nacional Mayor de San Marcos

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

Mg. Hansel Martínez Odiaga | Página N°89 | 2026—I
fO | = 1/[2π(L1CEQ)

1/2]

fO = 84.116 MHz

— Análisis de Parámetros FM

Consideramos los parámetros iniciales de Modulación FM:

Vm = 0.146 V

fm = 1 kHz

fC = 84.116 MHz

1.— Constante de Modulación FM

La Modulación FM ocurre porque el voltaje de audio altera el punto de operación del S9018. Esto varía la capacitancia interna de unión base—emisor del S9018. Luego, se sostiene:

kf = (fO/2)(MJC(MJE)

2CJE/CEQ)

kf = 66.082 kHz/V

2.— Desviación de Frecuencia Pico FM

Representa el cambio máximo que experimenta la frecuencia de portadora. Luego, se sostiene:

Δf = kfVm

Δf = 9.647 kHz

## Universidad Nacional Mayor de San Marcos

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

Mg. Hansel Martínez Odiaga | Página N°90 | 2026—I

3.— Frecuencia Instantánea FM

Representa la ecuación temporal que describe el cambio instantáneo de la frecuencia resultante.

f(t) = fO + Δfcos(2πfmt)

f(t) = 84.116×10⁶ + 9.647×10³

cos(2×10³πt) Hz

4.— Índice de Modulación FM

Relaciona la Desviación de Frecuencia Pico FM con la frecuencia de moduladora.

β = Δf/fm

β = 9.647

Nótese que se trata de Modulación FM de Banda Ancha (WBFM), dado que β > 1

5.— Ancho de Banda WBFM

El ancho de banda queda definido para Modulación FM de Banda Ancha (WBFM) como sigue:

W ∼ 2Δf

W ∼ 19.294 kHz

6.— Ancho de Banda FM con Regla de Carson

El ancho de banda según la Regla de Carson queda definido para casos intermedios como sigue:

W ∼ 2(Δf + fm)

W ∼ 21.294 kHz

## Universidad Nacional Mayor de San Marcos

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

Mg. Hansel Martínez Odiaga | Página N°91 | 2026—I

7.— Potencia Promedio de Portadora FM

Definimos los parámetros necesarios para los cálculos de potencia:

AC ∼ VBE = 0.8 V

RL = 10 kΩ

La potencia promedio de la señal portadora queda definida mediante J0(β) como sigue:

PC = (AC)
2

[J0(β)]²

/(2RL)

PC = 2 μW

8.— Potencia Promedio de Bandas Laterales FM

La potencia promedio de las bandas laterales queda definida mediante Jn(β) como sigue:

Pn = (AC)
2

[Jn(β)]²

/(RL)

Pn = 30 μW

9.— Potencia Promedio Total FM

La potencia promedio total queda definida mediante la señal portadora como sigue:

PT = (AC)
2

/(2RL)

PT = 32 μW

## Universidad Nacional Mayor de San Marcos

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

Mg. Hansel Martínez Odiaga | Página N°92 | 2026—I

— Análisis de Respuesta en Frecuencia

Figura N°79_ Bloque N°02: Diagrama Asintótico de Bode

## Universidad Nacional Mayor de San Marcos

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

Mg. Hansel Martínez Odiaga | Página N°93 | 2026—I

Figura N°80.1_ Tabla de Bessel de Primer Tipo

## Universidad Nacional Mayor de San Marcos

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

Mg. Hansel Martínez Odiaga | Página N°94 | 2026—I

Figura N°80.2_ Bloque N°02: Espectro FM

## Universidad Nacional Mayor de San Marcos

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

Mg. Hansel Martínez Odiaga | Página N°95 | 2026—I

Bloque N°03: Etapa Buffer + Amplificador RF

— Diagrama Esquemático

Figura N°81_ Bloque N°03: Diagrama Esquemático

— Componentes Electrónicos

Resistencia (R10): 47 kΩ
Capacitores Cerámicos (C10, C11, C12): 0.1 nF, 1 nF, 30 pF Bobinas (L3): 65 nH
Transistor BJT (Q3): S9018

## Universidad Nacional Mayor de San Marcos

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

Mg. Hansel Martínez Odiaga | Página N°96 | 2026—I

— Parámetros del Transistor Q3

1.— Parámetros de Corriente Directa

Corriente de Saturación de Transporte: IS [A] = 3×10⁻¹⁵
Ganancia de Corriente Máxima en Directo: βF = 102
Voltaje de Early en Directo: VAF [V] = 75
Corriente de Esquina en Caída de Ganancia en Directo: IKF [A] = 0.25 Corriente de Saturación de Fuga de Unión Base—Emisor: ISE [A] = 0.8×10⁻¹² Factor de Idealidad de Fuga de Unión Base—Emisor: NE = 2
Ganancia de Corriente Máxima en Inverso: βR = 0.3
Corriente de Esquina en Caída de Ganancia en Inverso: IKR [A] = 0.01 Corriente de Saturación de Fuga de Unión Base—Colector: ISC [A] = 0.8×10⁻¹² Factor de Idealidad de Fuga de Unión Base—Colector: NC = 2

2.— Parámetros de Resistencias Parásitas

Resistencia Óhmica de Base: RB [Ω] = 60
Resistencia Óhmica de Colector: RC [Ω] = 3.5

3.— Parámetros de Capacitancias Parásitas

Capacitancia de Depleción de Unión Base—Colector a Voltaje Cero: CJC [F] = 1.8×10⁻¹² Potencial de Contacto de Unión Base—Colector: VJC [V] = 0.8
Factor Exponencial de Unión Base—Colector: MJC = 0.15
Fracción de Capacitancia Base—Colector en Nodo de Base: XCJC = 0.1
Capacitancia de Depleción de Unión Base—Emisor a Voltaje Cero: CJE [F] = 1.5×10⁻¹² Potencial de Contacto de Unión Base—Emisor: VJE [V] = 0.8
Factor Exponencial de Unión Base—Emisor: MJE = 0.5
Coeficiente de Capacitancia de Unión en Directa: FC = 0.5

4.— Parámetros de Tiempo Transitorio

Tiempo de Tránsito Ideal de Carga de Base en Directo: TF [s] = 0.11×10⁻⁹ Tiempo de Tránsito Ideal de Carga de Base en Inverso: TR [s] = 2×10⁻⁹ Parámetro de Corriente en Tiempo de Tránsito Directo: ITF [A] = 13×10⁻³ Parámetro de Voltaje en Tiempo de Tránsito Directo: VTF [V] = 1.7 Coeficiente Exponencial en Tiempo de Tránsito Directo: XTF [V] = 3

## Universidad Nacional Mayor de San Marcos

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

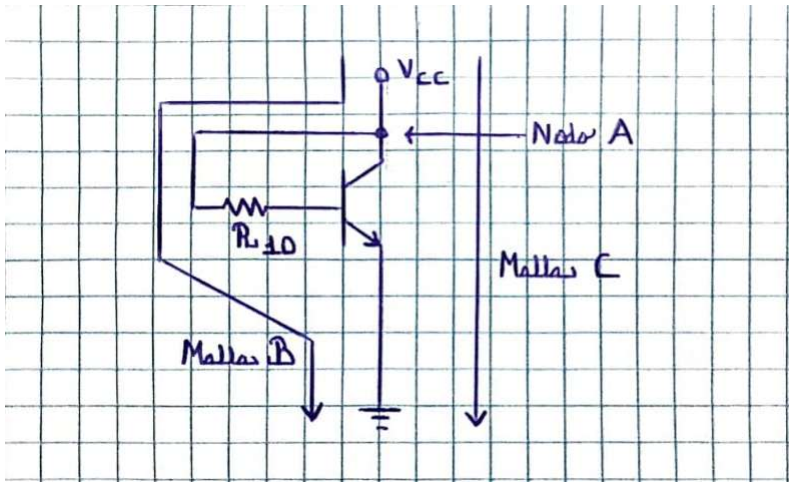
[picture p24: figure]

Mg. Hansel Martínez Odiaga | Página N°97 | 2026—I

5.— Parámetros de Temperatura

Exponente de Temperatura en Corriente de Saturación: XTI = 3 Exponente de Temperatura en Ganancia de Corriente: XTB = 1.5

6.— Parámetros de Especificaciones del Fabricante

Voltaje Máximo de Colector—Emisor en Base Abierta: VCEO [V] = 15 Corriente Máxima de Colector Recomendada: ICRATING [A] = 0.05 Fabricante del Componente: Fairchild

— Análisis DC

Figura N°82_ Bloque N°03: Circuito Equivalente DC

## Universidad Nacional Mayor de San Marcos

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

Mg. Hansel Martínez Odiaga | Página N°98 | 2026—I

De la Ley de Corrientes de Kirchhoff en el Nodo A:

ICC = IR10 + IC

ICC = IR10 + βIR10

ICC = (β + 1)IR10

De la Ley de Voltajes de Kirchhoff en la Malla B:

VCC − VR10 − VBE = 0

VCC − R10IR10 − VBE = 0

IR10 = IB = (VCC − VBE)/R10

De la Ley de Voltajes de Kirchhoff en la Malla C:

VCC − VCE = 0

VCE = VCC

De las ecuaciones obtenidas:

IB | = 0.174 mA
IC | = 17.74 mA
VCE | = 9 V

Q = (VCE, IC) = (9, 17.74)

## Universidad Nacional Mayor de San Marcos

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

Mg. Hansel Martínez Odiaga | Página N°99 | 2026—I

De la Resistencia Térmica a Temperatura Constante (VT ∼ 25 mV):

re = VT/ICC

re = VT/(IR7 + IC)

re = 1.39 Ω

De la Resistencia Intrínseca de Salida:

ro | = VAF/IC
ro | = 4.22 kΩ

— Análisis AC

Figura N°83_ Bloque N°03: Circuito Equivalente AC

Del análisis en la Red de Entrada:

## Universidad Nacional Mayor de San Marcos

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

Mg. Hansel Martínez Odiaga | Página N°100 | 2026—I

Zi = R10(1 − Av) || βre

Zi = 131.65 Ω

Del análisis de Reactancia Inductiva:

XL3 = 2πfOL3

XL3 = 34.35 Ω

Del análisis en la Red de Salida:

Zo | = XL3 || ro
Zo | = 34.07 Ω

De la Ley de Ohm en la Red de Entrada:

Vi = βIBre

De la Ley de Ohm en la Red de Salida:

Vo = −βIB(XL3 || ro)

Del análisis de Ganancia de Tensión:

Av = Vo/Vi

Av = −(XL3 || ro)/re

Av = −24.51

Del análisis de Ganancia de Potencia:

Ap = (Av)
2

(Zi/Zo)

Ap = 2321.32 ∼ 33.657 dB

## Universidad Nacional Mayor de San Marcos

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

Mg. Hansel Martínez Odiaga | Página N°101 | 2026—I

— Análisis de Respuesta en Frecuencia

Figura N°84_ Bloque N°03: Diagrama Asintótico de Bode

## Universidad Nacional Mayor de San Marcos

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

Mg. Hansel Martínez Odiaga | Página N°102 | 2026—I

Bloque N°04.1: Filtro de Salida

— Diagrama Esquemático

Figura N°85_ Bloque N°04.1: Diagrama Esquemático

— Componentes Electrónicos

Capacitores Cerámicos (C13, C14): 0.1 nF, 30 pF Bobinas (L3): 100 nH
Antena Dipolo de Media Onda: RL ∼ 50 Ω

— Análisis del Filtro de Salida

Figura N°86_ Bloque N°04.1: Análisis del Filtro de Salida

Considérese el sistema de ecuaciones que describe al Sistema de Control:

## Universidad Nacional Mayor de San Marcos

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

Mg. Hansel Martínez Odiaga | Página N°103 | 2026—I

sC12[Vi(s) − Vx(s)] = sC13Vx(s) + [Vx(s) − Vo(s)]/(sL4)

[Vx(s) − Vo(s)]/(sL4) = sC14Vo(s) + Vo(s)/RL

Del desarrollo del sistema de ecuaciones, se sostiene la Función de Transferencia:

Vo(s)/Vi(s) = H(s) = a(s)/b(s)

Donde:

a(s) = C12s

b(s) = [L4C14(C12 + C13)]s³ + [(L4/RL)(C12 + C13)]s² + [C12 + C13 + C14]s + (1/RL)

De la transformación al Dominio de la Frecuencia:

H(jw) = a(jw)/b(jw)

Donde:

a(jw) = C12jw

b(jw) = −j[L4C14(C12 + C13)]w

3 − [(L4/RL)(C12 + C13)]w

2 + j[C12 + C13 + C14]w + (1/RL)

Del análisis de Función Feedback:

b(jw) = {(1/RL) − [(L4/RL)(C12 + C13)]w
2

} + j{(C12 + C13 + C14)w − [L4C14(C12 + C13)]w
3

}

Del análisis del Módulo de Función de Transferencia:

|H(jw)| = |a(jw)|/|b(jw)|

Donde:

|a(jw)| = C12w

|b(jw)| = [({(1/RL) − [(L4/RL)(C12 + C13)]w
2

})² + ({(C12 + C13 + C14)w − [L4C14(C12 + C13)]w
3

})²

]
1/2

La resonancia del Sistema de Control ocurre cuando la parte imaginaria de b(jw) es nula:

## Universidad Nacional Mayor de San Marcos

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

Mg. Hansel Martínez Odiaga | Página N°104 | 2026—I

(C12 + C13 + C14)wo − [L4C14(C12 + C13)]wo

3 = 0

wo | = {(C12 + C13 + C14)/[L4C14(C12 + C13)]}¹/2
wo | = 640.512 Mrad/s
fo | = 101.94 MHz

De la aproximación de Ancho de Banda del Sistema de Control:

W ∼ 1/τ

W = 1/[RL(C12 + C13 + C14)]

W = 125 Mrad/s

B = W/2π = 19.89 MHz

De la aproximación de Frecuencia de Corte Inferior del Sistema de Control:

fCL | = fo − B/2
fCL | = 91.995 MHz

De la aproximación de Frecuencia de Corte Superior del Sistema de Control:

fCH = fo + B/2

fCH = 111.885 MHz

La Ganancia Máxima del Sistema de Control ocurre a la frecuencia de resonancia:

|H(jwo)| = |a(jwo)|/|b(jwo)|

|H(jwo)| = −3.08 dB

## Universidad Nacional Mayor de San Marcos

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

Mg. Hansel Martínez Odiaga | Página N°105 | 2026—I

— Análisis de Respuesta en Frecuencia

Figura N°87_ Bloque N°04.1: Diagrama Asintótico de Bode

## Universidad Nacional Mayor de San Marcos

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

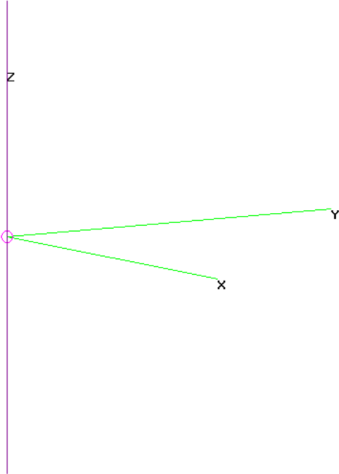
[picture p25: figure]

Mg. Hansel Martínez Odiaga | Página N°106 | 2026—I

Bloque N°04.2: Antena Transmisora

1.— Parámetros Iniciales de Diseño

Orientación: Antena Dipolo Polarizada Verticalmente

Longitud: λ/2 = 1.5 m

Entorno: Espacio Libre

Radio del Conductor: r = 0.005 m

Figura N°88_ Bloque N°04.2: Diseño de Antena Transmisora

## Universidad Nacional Mayor de San Marcos

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

Mg. Hansel Martínez Odiaga | Página N°107 | 2026—I

2.— Parámetros de Radiación: Análisis

— Dipolo Eléctrico Infinitesimal/Ideal

Conductor lineal que satisface:

d << h << λ

Donde:
d representa el diámetro del conductor del dipolo h representa la longitud del conductor del dipolo λ representa la longitud de onda del dipolo

Presenta distribución de corriente uniforme:

Figura N°89_ Distribución de Campos EM de Dipolo Ideal

## Universidad Nacional Mayor de San Marcos

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

Mg. Hansel Martínez Odiaga | Página N°108 | 2026—I

— Análisis del Campo Electromagnético

Figura N°90_ Definición Matemática de Campos EM de Dipolo Ideal

Donde:
I0 representa la corriente en el punto de alimentación del dipolo η representa la impedancia intrínseca del medio

Resultados:
Las ondas EM se propagan en dirección radial
Para cualquier (r, t) se presenta un frente de ondas de fase constante
El dipolo ideal genera familia de fuentes de frente de ondas esféricas

— Campo Cercano o de Inducción
Análisis para puntos próximos a la antena (r → 0):

Figura N°91_ Definición Matemática de Campos EM Cercanos de Dipolo Ideal

— Campo Lejano o de Radiación

## Universidad Nacional Mayor de San Marcos

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

Mg. Hansel Martínez Odiaga | Página N°109 | 2026—I

Análisis para puntos lejanos a la antena (r >> λ):

Figura N°92_ Definición Matemática de Campos EM Lejanos de Dipolo Ideal

Resultados:
Campos EM con propiedades similares a las de una onda plana

— Potencia Radiada por el Dipolo Infinitesimal

Vector de Poynting

Figura N°93_ Definición Matemática de Vector de Poynting del Dipolo Ideal

Valor Promedio del Vector de Poynting

Figura N°94_ Definición Matemática de Vector de Poynting Promedio del Dipolo Ideal

Potencia Radiada por el Dipolo Infinitesimal

## Universidad Nacional Mayor de San Marcos

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

Mg. Hansel Martínez Odiaga | Página N°110 | 2026—I

Figura N°95_ Definición Matemática de Potencia Radiada del Dipolo Ideal

— Parámetros del Diagrama de Radiación

Figura N°96_ Modelo General del Diagrama de Radiación

Lóbulo Principal
Lóbulo que contiene la dirección de máxima radiación

Lóbulos Menores
Lóbulos con menor radiación que el principal

Nulos
Puntos donde el diagrama de radiación se anula

Ancho de Haz para Media Potencia Separación angular entre puntos de media potencia

— Directividad. Eficiencia. Ganancia

## Universidad Nacional Mayor de San Marcos

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

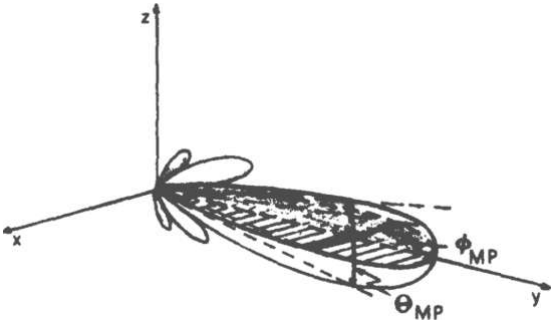
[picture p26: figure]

Mg. Hansel Martínez Odiaga | Página N°111 | 2026—I

Directividad
Propiedad de transmitir/recibir más potencia en una dirección dada

Figura N°97_ Cálculo de Directividad de Antena Transmisora

Ángulo Sólido de Haz

Figura N°98_ Cálculo del Ángulo Sólido de Haz de Antena Transmisora

Eficiencia
Relación entre potencia radiada (WT), potencia del transmisor (Wt) Relación entre potencia del receptor (Wr), potencia recibida (WR)

## Universidad Nacional Mayor de San Marcos

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

Mg. Hansel Martínez Odiaga | Página N°112 | 2026—I

Figura N°99_ Cálculo de Eficiencia de Antena Transmisora

Ganancia
Producto de la Directividad con la Eficiencia

— Potencia Efectiva Radiada Isotrópicamente
Producto de Potencia del transmisor con la Ganancia de Antena

— Impedancia de Entrada
Representa la impedancia en los terminales de conexión

Figura N°100_ Circuito Equivalente General de Impedancia de Entrada

Principio de Conservación de Potencia

## Universidad Nacional Mayor de San Marcos

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

Mg. Hansel Martínez Odiaga | Página N°113 | 2026—I

Figura N°101_ Formulación del Principio de Conservación de Potencia

Resultados:

Figura N°102_ Deducción de Resistencia/Eficiencia de Radiación

Donde:
Wp representa la Potencia de Pérdidas Óhmicas Rr representa la Resistencia de Radiación
Rp representa la Resistencia de Pérdidas Óhmicas

Figura N°103_ Cálculo de Resistencia de Radiación de Antena Transmisora

Análisis de Reactancia de Entrada
Depende de las propiedades de la Línea de Transmisión De la Línea de Transmisión sin pérdidas con longitud l:

## Universidad Nacional Mayor de San Marcos

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

Mg. Hansel Martínez Odiaga | Página N°114 | 2026—I

Figura N°104_ Impedancia de Entrada General en Línea de Transmisión sin Pérdidas

Del análisis de dicha línea en circuito abierto:

Figura N°105_ Reactancia de Entrada General en Línea de Transmisión sin Pérdidas

De la Reactancia en función de la longitud eléctrica de la antena:

Figura N°106_ Reactancia de Entrada General Vs. Longitud Eléctrica de Antena

— Área Efectiva
Área equivalente de extracción de toda la potencia recibida

## Universidad Nacional Mayor de San Marcos

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

Mg. Hansel Martínez Odiaga | Página N°115 | 2026—I

Figura N°107_ Definición Matemática del Área Efectiva

Figura N°108_ Circuito Equivalente General de Antena Receptora

Del análisis para el Dipolo Ideal:

Área Efectiva

Figura N°109_ Deducción Matemática del Área Efectiva de Antena Dipolo Ideal

Área Efectiva Máxima

## Universidad Nacional Mayor de San Marcos

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

Mg. Hansel Martínez Odiaga | Página N°116 | 2026—I

Figura N°110_ Cálculo del Área Efectiva Máxima de Antena Transmisora

— Longitud Efectiva
Longitud equivalente con distribución de corriente uniforme que produce el mismo efecto de campo lejano

Figura N°111_ Cálculo de Longitud Efectiva de Antena Transmisora

Figura N°112_ Diagrama Equivalente de Longitud Efectiva

PROCEDIMIENTO DE SIMULACIONES

## Universidad Nacional Mayor de San Marcos

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

Mg. Hansel Martínez Odiaga | Página N°117 | 2026—I

Bloque N°01: Fuente de Audio + Preamplificador de Audio

1.— Creación de Nuevo Proyecto

Figura N°113_ Creación de Nuevo Proyecto en Altium Designer

Descripción:
Realizamos la creación de un Nuevo Proyecto en el software Altium Designer. El nombre del proyecto es FM.

2.— Creación de Nuevo Esquemático

## Universidad Nacional Mayor de San Marcos

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

Mg. Hansel Martínez Odiaga | Página N°118 | 2026—I

Figura N°114_ Creación de Nuevo Esquemático en el Proyecto FM

Descripción:
Dentro del proyecto FM, añadimos un Schematic para implementar el Diagrama Esquemático.

3.— Instalación de Altium Library Loader

## Universidad Nacional Mayor de San Marcos

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

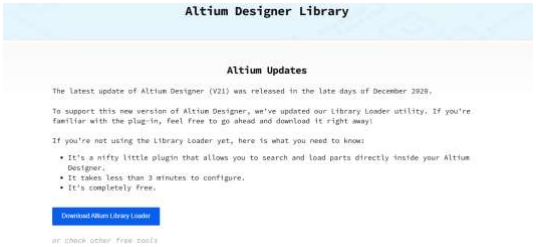
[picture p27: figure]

Mg. Hansel Martínez Odiaga | Página N°119 | 2026—I

Figura N°115_ Descarga/Instalación de Altium Library Loader

Descripción:
Ingresamos al enlace de descarga de Altium Designer Library (véase las referencias). Descargamos la aplicación en la opción Download Altium Library Loader.

4.— Descarga de Footprints

## Universidad Nacional Mayor de San Marcos

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

Mg. Hansel Martínez Odiaga | Página N°120 | 2026—I

Figura N°116_ Descarga de Footprints: S9014, S918

Descripción:
Ingresamos al enlace de repositorio de SamacSys (véase las referencias).
Dentro, buscamos los transistores que necesitamos: S9014, S9018.
Luego, descargamos sus modelos para continuar con la implementación en Altium Designer.

5.— Adjunte de Footprints

## Universidad Nacional Mayor de San Marcos

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

Mg. Hansel Martínez Odiaga | Página N°121 | 2026—I

Figura N°117_ Adjunte de Footprints en Altium Library Loader: S9014, S918

Descripción:
Luego de descargar los modelos requeridos, obtendremos dos archivos en el formato .epw Ambos se adjuntan en Altium Library Loader mediante la opción OPEN ECAD MODEL

6.— Modelos Esquemáticos S9014, S9018

## Universidad Nacional Mayor de San Marcos

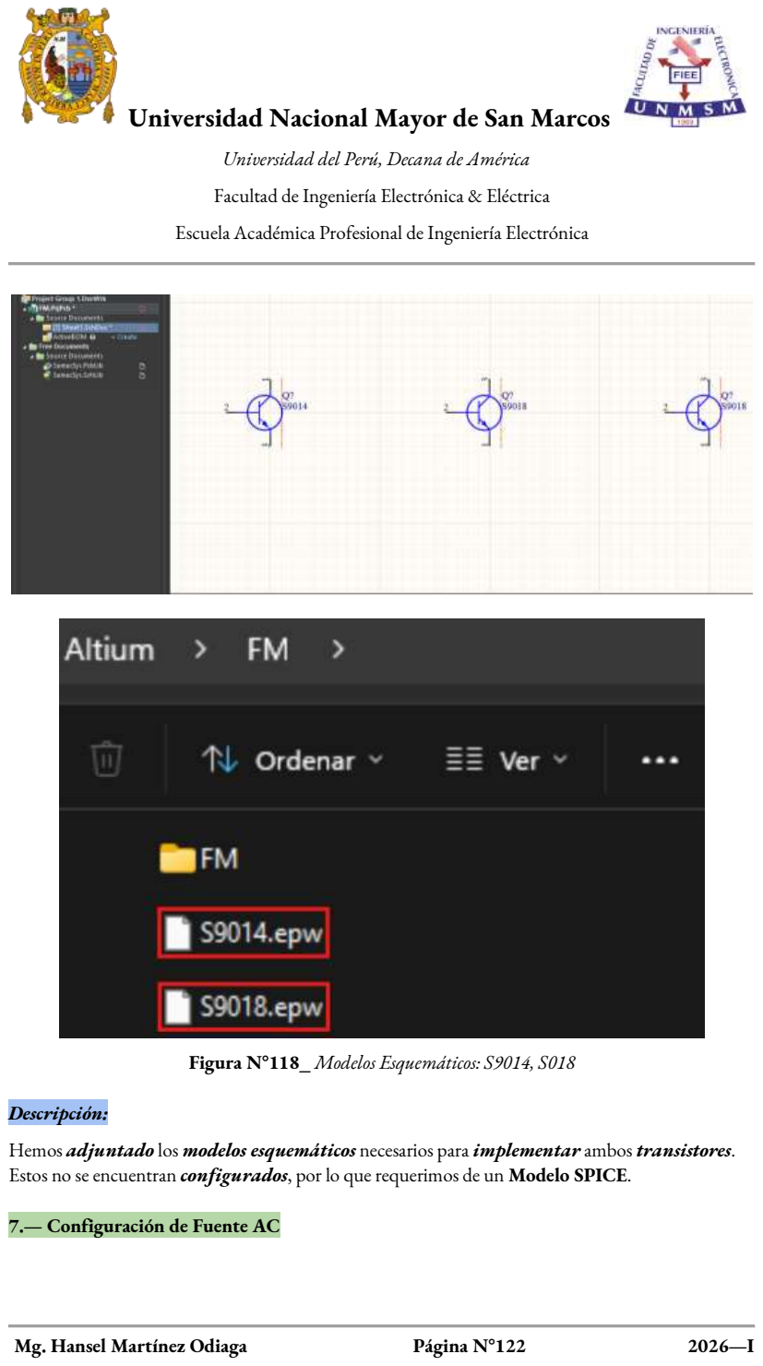
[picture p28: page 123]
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

Mg. Hansel Martínez Odiaga | Página N°122 | 2026—I

Figura N°118_ Modelos Esquemáticos: S9014, S018

Descripción:
Hemos adjuntado los modelos esquemáticos necesarios para implementar ambos transistores. Estos no se encuentran configurados, por lo que requerimos de un Modelo SPICE.

7.— Configuración de Fuente AC

## Universidad Nacional Mayor de San Marcos

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

Mg. Hansel Martínez Odiaga | Página N°123 | 2026—I

Figura N°119_ Configuración de Fuente de Alimentación AC

Descripción:
Configuramos una Fuente AC que representa la Señal Moduladora FM. La amplitud de 5 mV, la frecuencia de 1 kHz

8.— Configuración de Fuente DC

## Universidad Nacional Mayor de San Marcos

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

Mg. Hansel Martínez Odiaga | Página N°124 | 2026—I

Figura N°120_ Configuración de Fuente de Alimentación DC

Descripción:
Configuramos una Fuente DC que representa la alimentación continua del Transmisor FM. La magnitud establecida es de 9 VDC

9.— Modelos de Componentes Generales

Figura N°121_ Adjunte de Modelos de Componentes Generales

Descripción:
En la pestaña de Componentes se encuentran los modelos predeterminados que usaremos.

10.— Creación de Modelo SPICE

Creamosambos Modelos SPICE (S9014, S9018) directamente con los datos del Datasheet.

## Universidad Nacional Mayor de San Marcos

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

Mg. Hansel Martínez Odiaga | Página N°125 | 2026—I

(véase las referencias)

Modelo SPICE: S9014

.MODEL S9014 NPN (
+ IS=2.68E-14 BF=320 NF=1.0 VAF=80 IKR=0.14

+ ISE=1.2E-14 NE=1.5 BR=4 NR=1.0 VAR=20
+ IKR=0.01 ISC=0 NC=2 RB=10 IRB=0.1
+ RBM=1 RE=0.4 RC=0.8 CJE=2.2E-11 VJE=0.75

+ MJE=0.33 CJC=7.5E-12 VJC=0.75 MJC=0.33 + TF=5E-10 TR=1E-8 EG=1.11 XTI=3 VCEO=45 + ICRATING=100m mfg=Fairchild)
Modelo SPICE: S9018

.MODEL S9018 NPN (
+ IS=3f XCJC=0.1 XTI=3 VAF=75 BF=102 NE=2

+ ISE=0.8p IKF=250m XTB=1.5 BR=0.3 NC=2
+ ISC=0.8p IKR=10m RC=3.5 CJC=1.8p MJC=0.15 + VJC=0.8 FC=0.5 CJE=1.5p MJE=0.5 VJE=0.8

+ TR=2n TF=110p ITF=13m VTF=1.7 XTF=3
+ RB=60 VCEO=15 ICRATING=50m mfg=Fairchild)
Guardamos ambos Modelos SPICE utilizando el formato .lib

Figura N°122_ Modelos SPICE en Formato .lib

Seleccionamos las propiedades del transistor; luego, seleccionamosel apartado de Simulación.

## Universidad Nacional Mayor de San Marcos

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

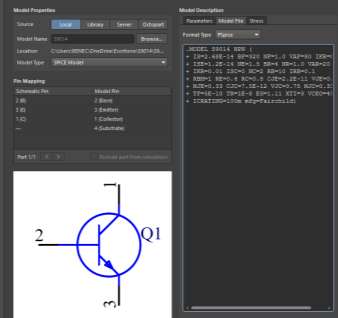
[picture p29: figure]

Mg. Hansel Martínez Odiaga | Página N°126 | 2026—I

Figura N°123_ Apartado de Propiedades del Transistor Seleccionado

En el apartado de Model Description, seleccionamos la opción Model File — PSpice. Adjuntamosel archivo .lib asociado al transistor que hemos seleccionado.

Figura N°124_ Adjunte de Modelo SPICE del Transistor S9014

## Universidad Nacional Mayor de San Marcos

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

Mg. Hansel Martínez Odiaga | Página N°127 | 2026—I

Figura N°125_ Adjunte de Modelo SPICE del Transistor S9018

11.— Etapa de Preamplificación de Audio

Figura N°126_ Etapa de Preamplificación de Audio
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

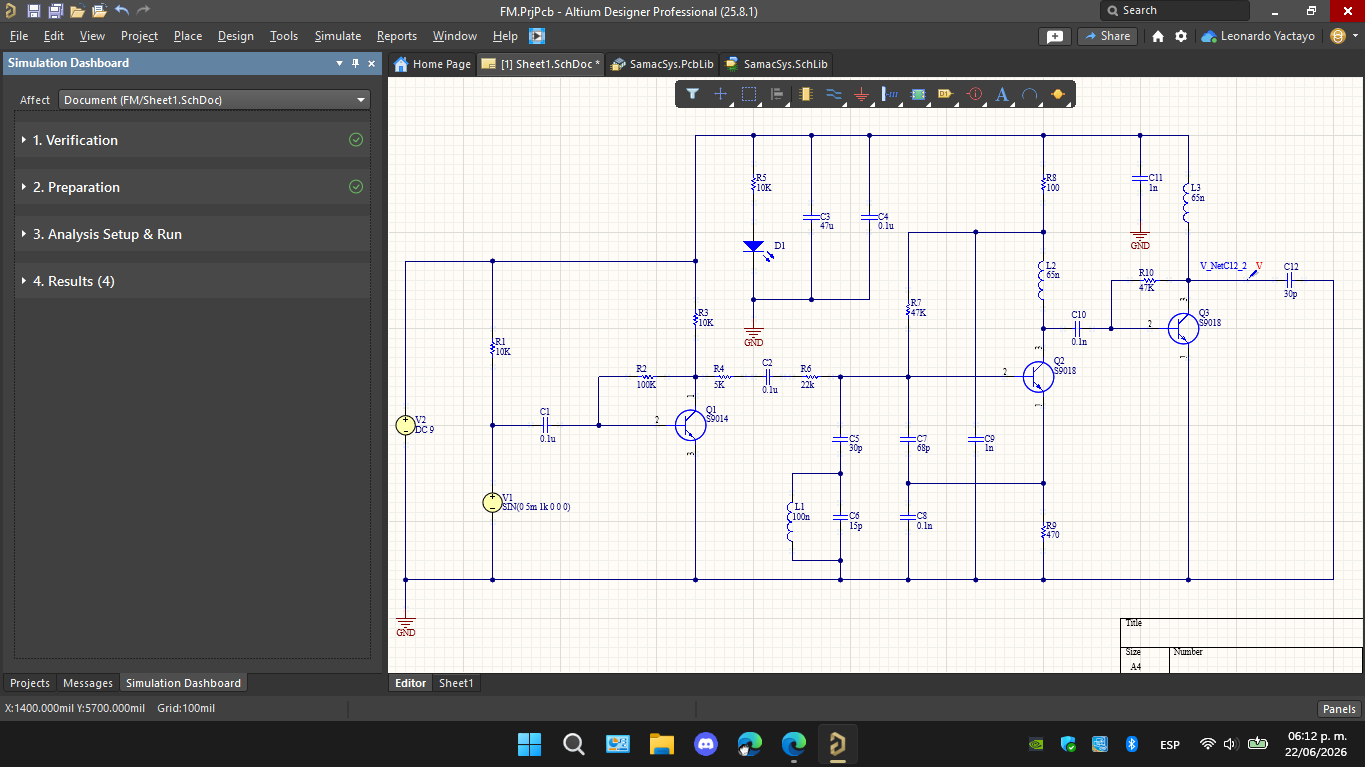
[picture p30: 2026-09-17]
simulation/captures/altium_designer/[22] Etapa Amplificador RF.png

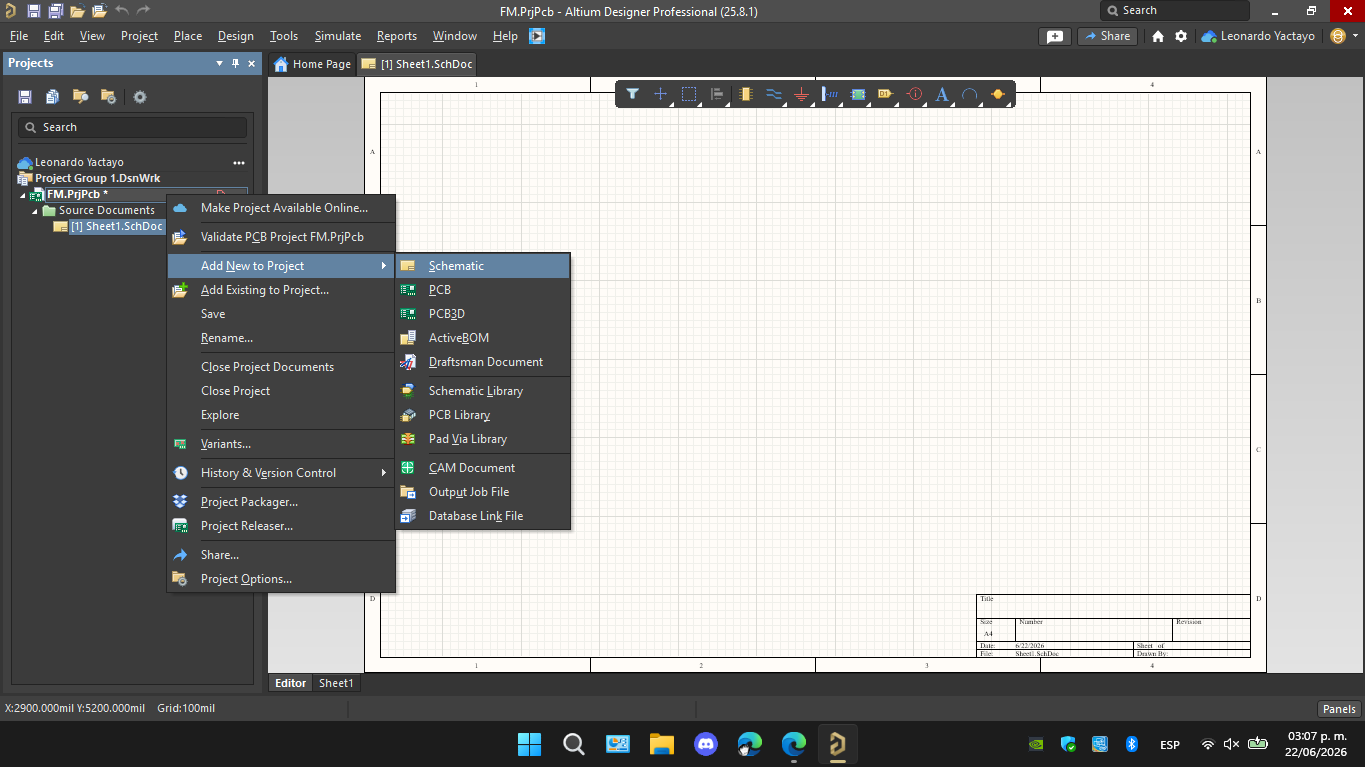
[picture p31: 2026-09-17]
simulation/captures/altium_designer/[2] Creación de Nuevo Esquemático.png

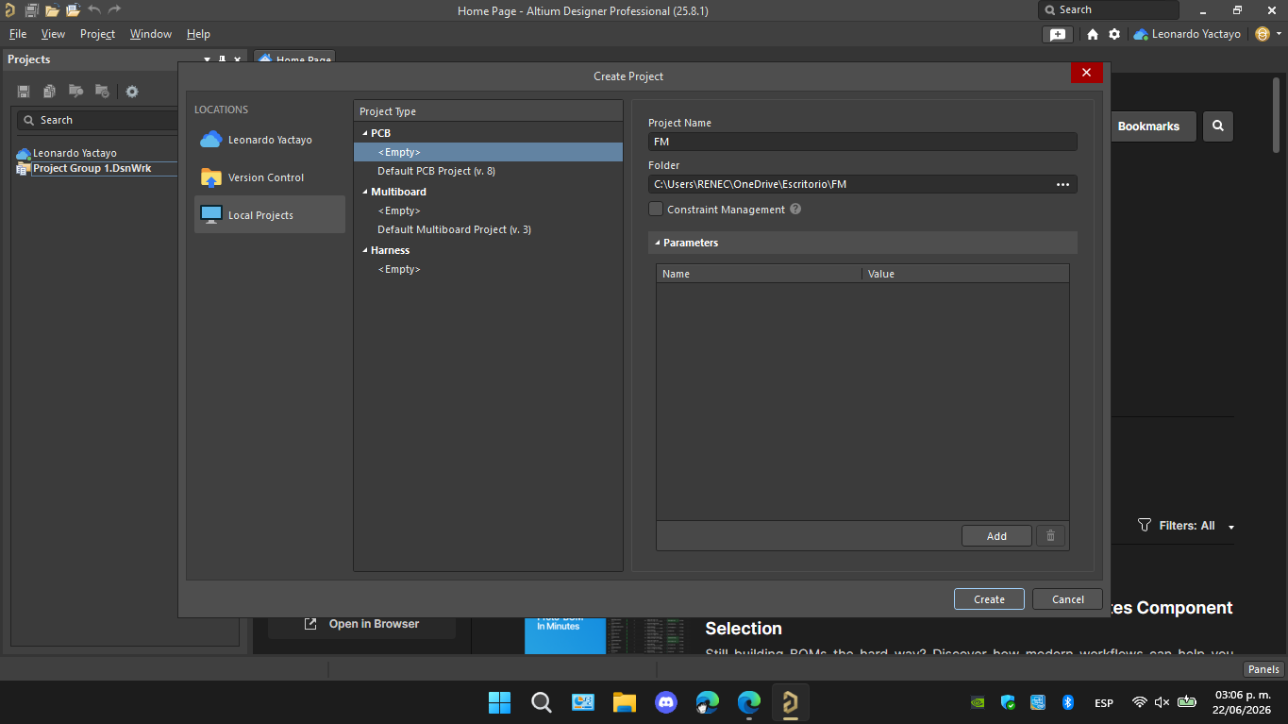
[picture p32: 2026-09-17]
simulation/captures/altium_designer/[1] Creación de Nuevo Proyecto.png

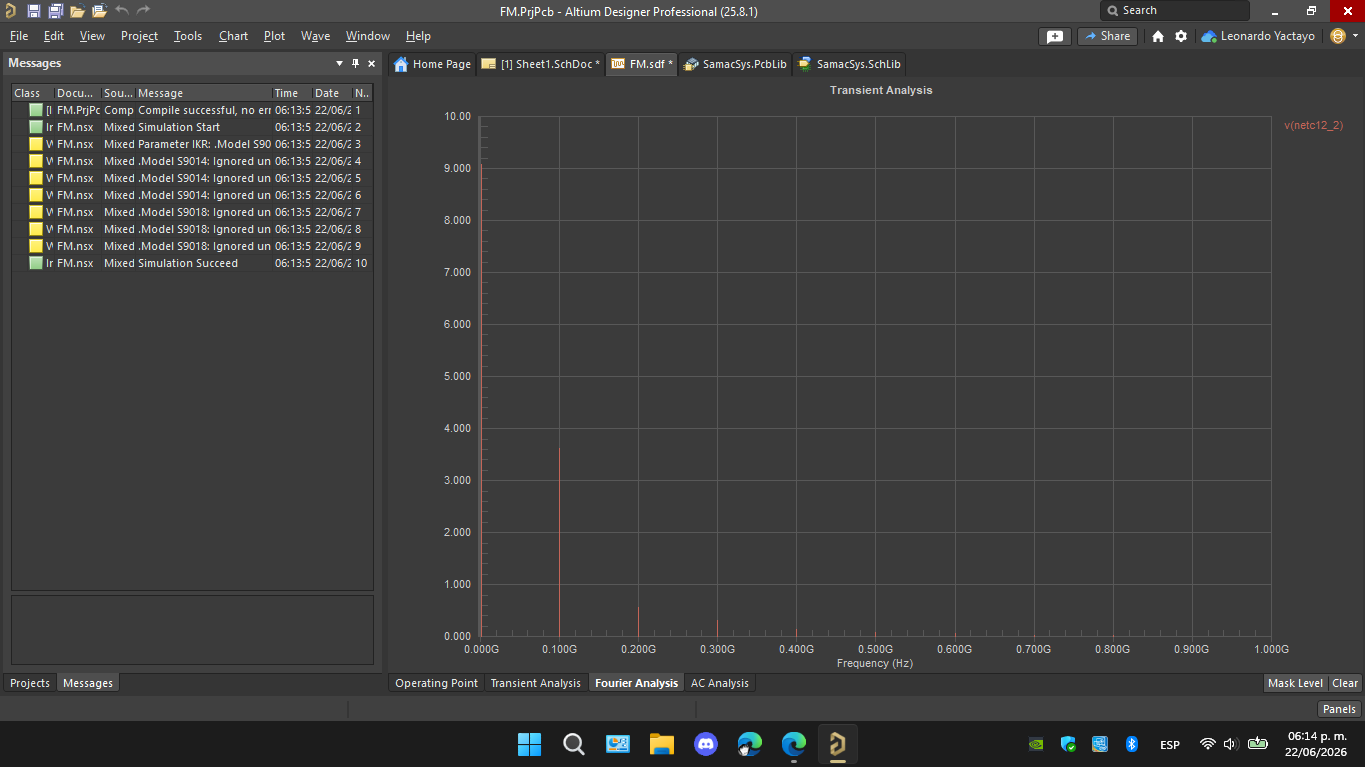
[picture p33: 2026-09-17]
simulation/captures/altium_designer/[26] Respuesta FOURIER.png

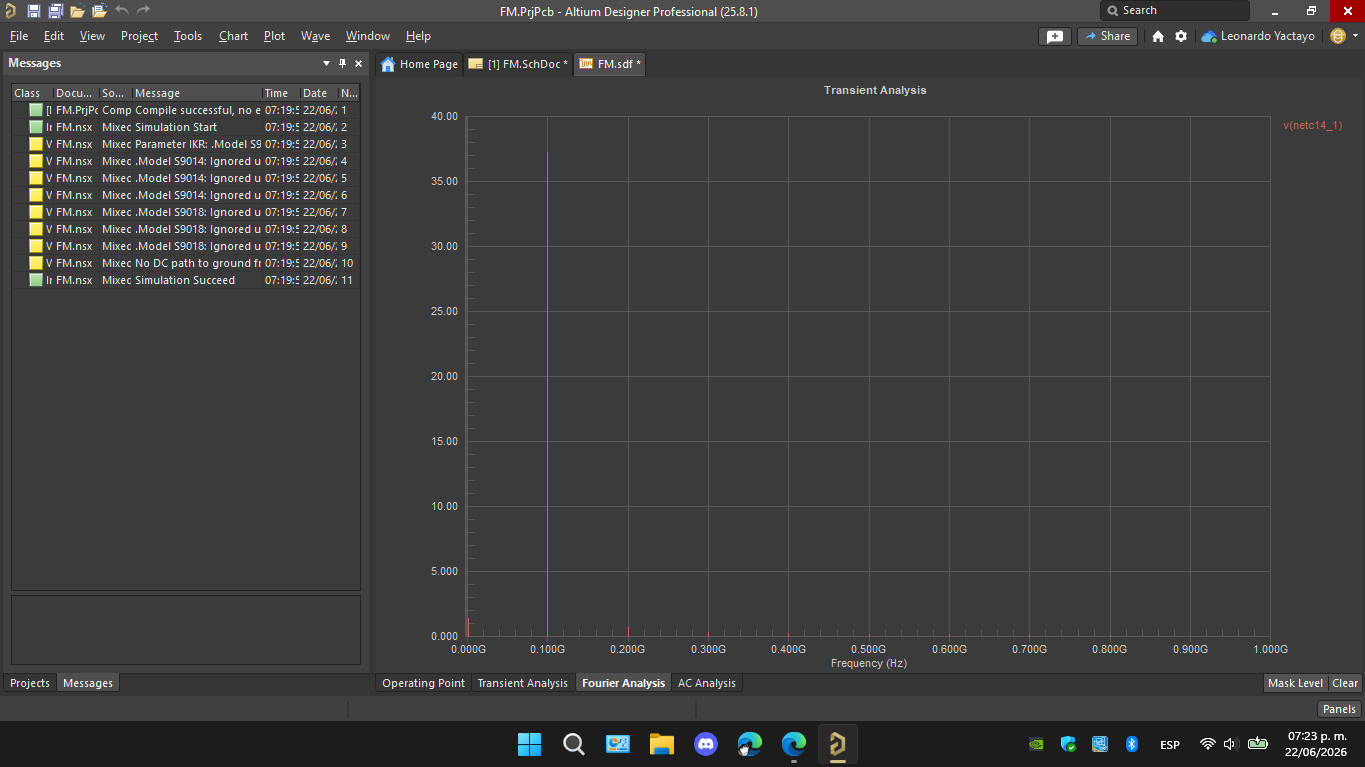
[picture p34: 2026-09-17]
simulation/captures/altium_designer/[32] Respuesta FOURIER.png

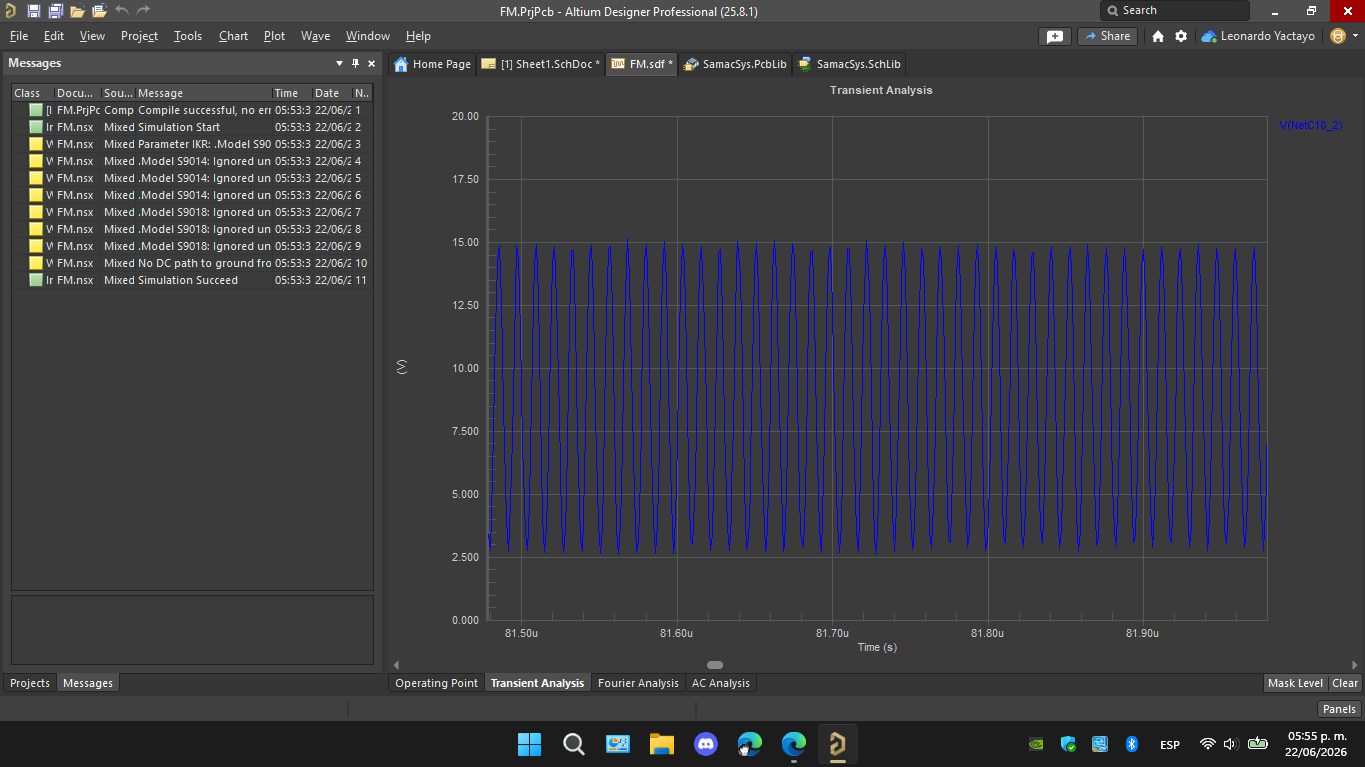
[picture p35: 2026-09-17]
simulation/captures/altium_designer/[19] Respuesta TRANSIENT.png
